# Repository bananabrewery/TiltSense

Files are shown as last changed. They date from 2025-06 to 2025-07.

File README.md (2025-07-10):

<div align="center">
  TiltSense
</div>

## TiltSense

**TiltSense** is a flexible and powerful ESP32-based system that brings together multiple sensors, integrations, and
user-friendly tools into a single customizable hub for fermentation monitoring.

After months of design, development, and testing, the first stable release is finally out of the oven — and it's packed
with features for homebrewers, hackers, and fermentation geeks alike.

🧪 The complete documentation is now available at:  
👉 [https://bananabrewery.github.io/TiltSense](https://bananabrewery.github.io/TiltSense)

---

## 📦 Project Status

TiltSense is stable and fully functional in its first release. The current firmware is offered as a complete example
configuration.

🛠️ **Ongoing development:**  
A **TiltSense Firmware Builder** is available — a web app that generates fully customized firmware tailored to your specific setup, eliminating manual editing.

- ✅ Which **Tilt hydrometers** are used, and their **colors**
- 🆚 Whether they are **Tilt** or **Tilt Pro** versions
- 🏠 Whether the user has **Home Assistant** integration
- 💨 Whether a **pressure sensor** is included
- 📡 Whether integration with **Brewfather** is desired

This simplifies setup and allows adapting TiltSense to a wide variety of fermentation scenarios.

Check out the Firmware Builder here:  
👉 [https://bananabrewery.github.io/TiltSenseFirmwareBuilder](https://bananabrewery.github.io/TiltSenseFirmwareBuilder)

I’ve also developed a backend compiler service that can build your firmware automatically — no local ESPHome install
needed!

---

## 🚀 Features

- **✅ Multi-Tilt Support**  
  Read and monitor multiple [Tilt Hydrometers](https://tilthydrometer.com/) simultaneously, including standard and Pro
  models.

- **📡 Brewfather & Home Assistant Integration**  
  Native support for seamless tracking, automation, and remote data logging.

- **🌐 Built-in Web Server**  
  Configure system parameters via an intuitive and mobile-friendly web interface.

- **🔀 Sensor Fusion**  
  Combine Tilt data with pressure sensors for real-time fermentation profiling (e.g., gravity curves under pressure).

- **🔋 Internal Battery**  
  Portable and continuous operation with low-power consumption and battery support.

- **🧲 Magnetic 3D-Printed Enclosure**  
  Custom-designed case with magnetic mounting — easy to use, easy to love.

- **💡 Touchscreen Interface**  
  Clean LVGL-powered display with gesture-based navigation, real-time feedback, and interactive widgets.

- **💰 Affordable & Accessible**  
  Built using low-cost, off-the-shelf ESP32 hardware and open-source components.

---

## 📷 Screenshots

<div align="center">
  TiltSense Screen
</div>

---

## 📦 Hardware Requirements

Here’s what you need to build a complete TiltSense unit:

- [**ESP32-S3 with 1.28" Round Touchscreen**
  (GC9A01A display + CST816S capacitive touch)](https://s.click.aliexpress.com/e/_oBHq2mi)  
  A compact, all-in-one ESP32-S3 development board with integrated round LCD and touchscreen.

- [**LiPo Battery 3.7V (1S) 200mAh with JST 1.25mm connector**](https://s.click.aliexpress.com/e/_op2Asqw)  
  Optional but supported.  
  ⚠️ **Important**: Check polarity before connecting. Some batteries come with inverted pins!

- [**M2xL2xOD3.2 Brass Heat-Set Inserts**](https://s.click.aliexpress.com/e/_okAnuHg)  
  For securing the case with threaded inserts.

- [**M2x5mm Screws**](https://s.click.aliexpress.com/e/_omZDYlo)  
  To mount the case and secure the board.

- [**Neodymium Magnet 20×3 mm**](https://s.click.aliexpress.com/e/_okD0ylg)  
  Embedded in the 3D-printed case for easy magnetic mounting on fermenters or fridges.

- [**3D-Printed Case**](https://makerworld.com/en/models/1509302-tiltsense#profileId-1580036)  
  A custom enclosure designed for easy assembly, battery integration, and magnetic mounting.  
  🖨️ **Print instructions are available
  on [MakerWorld](https://makerworld.com/en/models/1509302-tiltsense#profileId-1580036)**.

- [**USB-A to USB-C Cable**](https://s.click.aliexpress.com/e/_oCeMiAi)  
  For flashing firmware and charging the internal battery.

- **Pressure Sensor** *(optional — details coming soon)*  
  Used for advanced fermentation tracking by monitoring internal vessel pressure.

🖨️ Print instructions are available on [MakerWorld](https://makerworld.com/en/models/1509302-tiltsense#profileId-1580036)

---

## 🔧 Setup & Flashing

1. Configure and generate your custom firmware using the Firmware Builder:  
   👉 [https://bananabrewery.github.io/TiltSenseFirmwareBuilder/](https://bananabrewery.github.io/TiltSenseFirmwareBuilder/)

2. You can either:
    - Compile the firmware yourself using ESPHome, or
    - Use the backend compiler service integrated in the Firmware Builder to generate a ready-to-flash binary.

3. Flash your ESP32 using [ESPHome](https://web.esphome.io) with the firmware file.

4. Access the web UI via mDNS or IP (`http://tiltsense.local/`).

---

## 🤝 Integrations

- [Tilt Hydrometer](https://tilthydrometer.com/)
- [Brewfather](https://brewfather.app/)
- [Home Assistant](https://www.home-assistant.io/)

--- 

## 🛠️ Setup & Development Environment

### 1. Create a virtual environment

Make sure you have Python 3 installed. Then, in the root of the project, create a virtual environment:

```bash
python3 -m venv .venv
```

Activate the virtual environment:

```bash
source .venv/bin/activate
```

### 2. Install project dependencies

Once the virtual environment is active, install the required packages:

```bash
pip install -r requirements.txt
```

### 3. Serve the documentation (MkDocs)

To serve the documentation locally:

```bash
mkdocs serve
```

This will start a local server at:

```bash
http://127.0.0.1:8000/
```

MkDocs will automatically reload when you make changes to the documentation files.

### 4. Build the static site (optional)

To generate the static site in the site/ directory:

```bash
mkdocs build
```

This is useful if you want to deploy the documentation (e.g. to GitHub Pages).

---

## 🙋 Community & Support

- ❗ Report bugs or request features: [Open an issue](https://github.com/bananabrewery/TiltSense/issues)
- 💬 Share ideas and ask questions: [Join the discussion](https://github.com/bananabrewery/TiltSense/discussions)
- 🤝 Want to help? Contributions are welcome!

---

## 📝 License

This project is licensed under the [MIT License](LICENSE).

---

## ❤️ Acknowledgements

TiltSense is built with love using:

- [ESPHome](https://esphome.io/)
- [LVGL](https://lvgl.io/)
- [Tilt](https://tilthydrometer.com/)
- Community feedback and personal fermentation obsession 🧪🍻

Special thanks to [Llupols](https://github.com/llupols) for designing the TiltSense logo. Your creativity and talent
have given our project a unique identity. Much appreciated!

---

## 🙌 Contribute

Pull requests are welcome! Fork the repo, improve the code or docs, and open a PR.  
You can also contribute by sharing feedback or joining discussions.

---

## 📣 Stay tuned

More features, documentation, and exciting new hardware coming soon!

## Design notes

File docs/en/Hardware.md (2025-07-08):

---
title: Hardware Requirements
description: Complete list of components required to build a TiltSense device, including the ESP32-S3 board, battery, case, and accessories.
icon: material/cube
---

# Hardware Requirements

This section outlines the complete list of hardware components required to assemble a functional **TiltSense** device.
The chosen components are optimized for compactness, reliability, and ease of assembly, leveraging widely available and
affordable parts.

## Required Components

### 🔹 ESP32-S3 with 1.28" Round Touchscreen

[Buy on AliExpress](https://s.click.aliexpress.com/e/_oBHq2mi)

<div align="center">
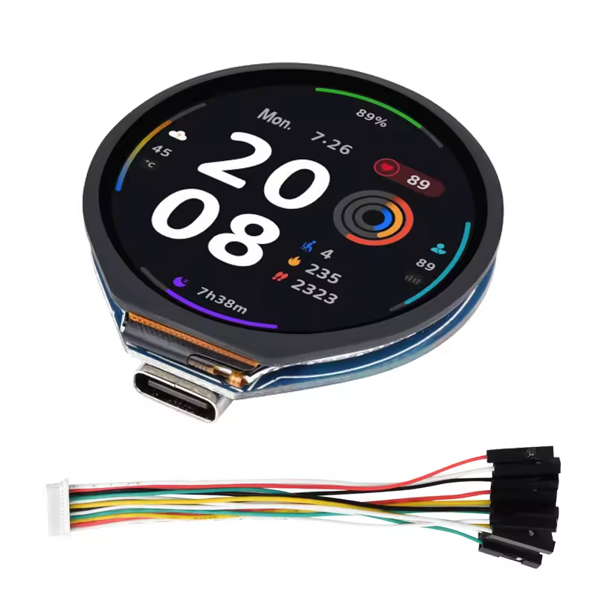
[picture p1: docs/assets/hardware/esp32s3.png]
TiltSense ESP32-S3
  
</div>

A compact, all-in-one ESP32-S3 development board featuring:

- A 1.28" round **GC9A01A** TFT LCD
- **CST816S** capacitive touch interface
- Onboard USB-C, charging circuitry, and GPIO access

> 📌 This is the core of the TiltSense system. Make sure your version includes both the GC9A01A display and CST816S touch
> controller.

For technical details, pinouts, and specifications, refer to the official Waveshare documentation:  
🔗 [ESP32-S3-Touch-LCD-1.28 — Waveshare Wiki](https://www.waveshare.com/wiki/ESP32-S3-Touch-LCD-1.28)

---

### 🔋 LiPo Battery – 3.7V (1S) 200mAh with JST 1.25mm Connector

[Buy on AliExpress](https://s.click.aliexpress.com/e/_op2Asqw)

<div align="center">
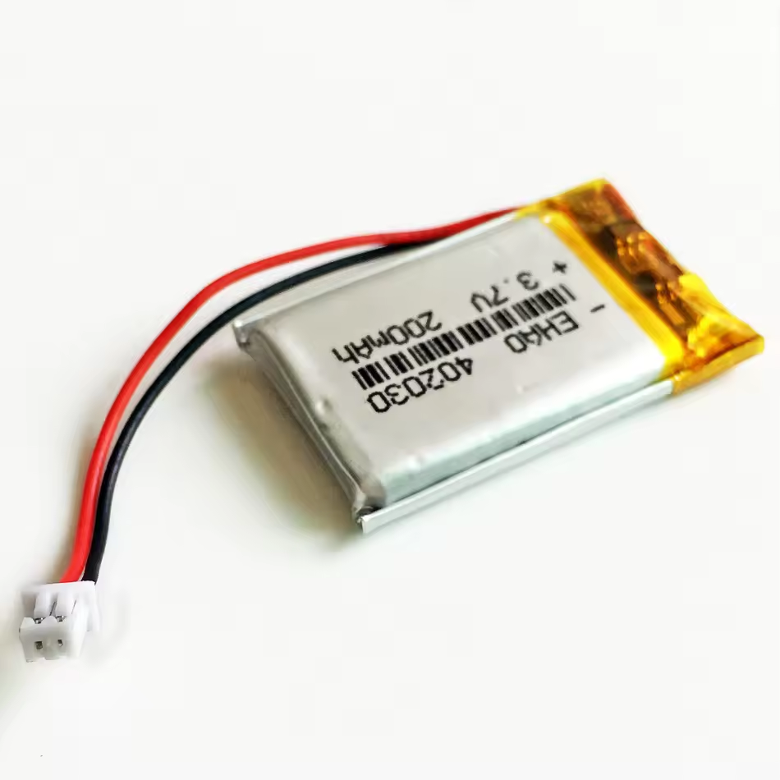
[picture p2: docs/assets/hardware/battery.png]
TiltSense Battery
  
</div>

A small rechargeable lithium battery that powers the device when disconnected from USB.

- Optional but supported
- Provides approx. 45 minutes of runtime
- Useful for safe relocation or in case of temporary power loss

> ⚠️ **Important**: Always verify **polarity** before connecting the battery. Some suppliers use inverted connectors
> which may damage the board.

---

### 🔩 M2 Brass Heat-Set Inserts

[Buy on AliExpress](https://s.click.aliexpress.com/e/_okAnuHg)

<div align="center">
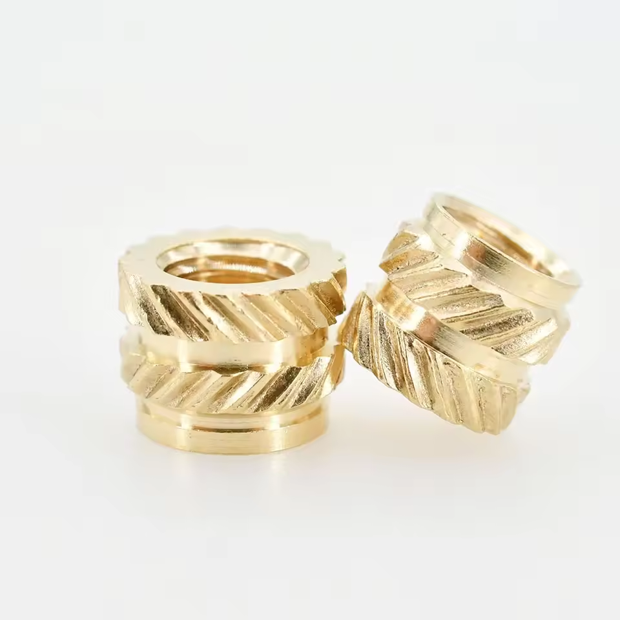
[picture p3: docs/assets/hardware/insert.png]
TiltSense M2 Insert
  
</div>

Heat-set inserts used to reinforce the mounting points of the 3D-printed enclosure:

- Dimensions: **M2 × L2 mm × OD3.2 mm**
- Installed with a soldering iron or insert tool

---

### 🔧 M2x5mm Screws

[Buy on AliExpress](https://s.click.aliexpress.com/e/_omZDYlo)

<div align="center">
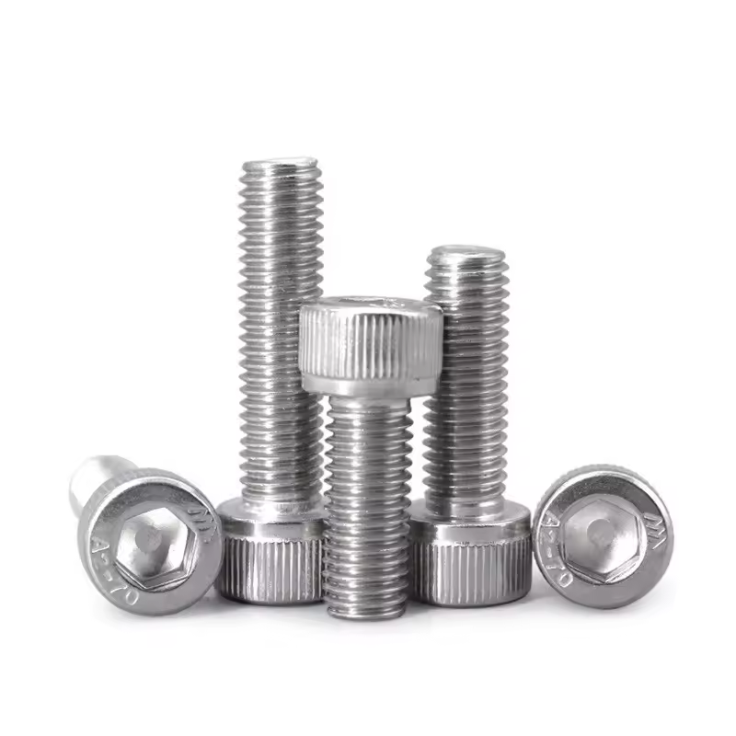
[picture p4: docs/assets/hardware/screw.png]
TiltSense Screw
  
</div>

Small metric screws to secure the ESP32 board to the case and fasten the enclosure parts.

---

### 🧲 Neodymium Magnet – 20×3mm

[Buy on AliExpress](https://s.click.aliexpress.com/e/_okD0ylg)

<div align="center">
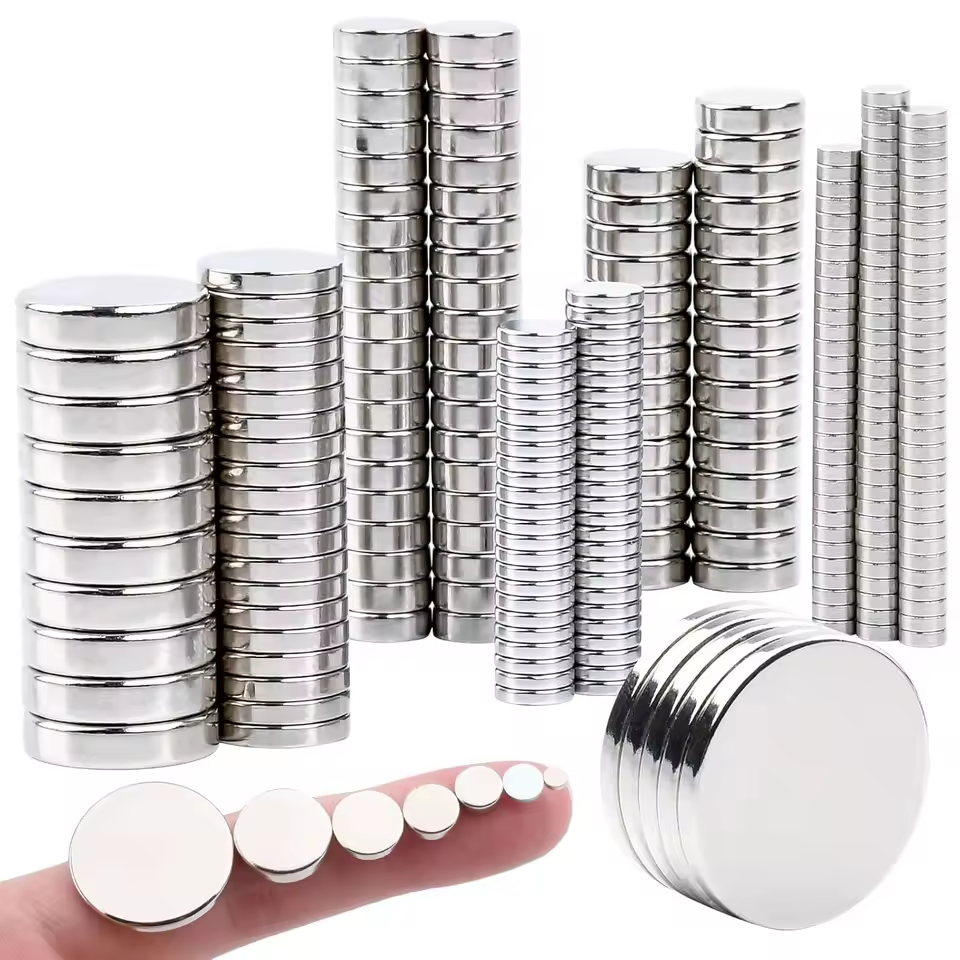
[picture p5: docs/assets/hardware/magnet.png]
TiltSense Magnet
  
</div>

A circular magnet embedded in the rear of the case, allowing the device to attach firmly to metal surfaces like
fermentation chambers or kegerators.

---

### 🖨️ 3D-Printed Enclosure

[Download from MakerWorld](https://makerworld.com/en/models/1509302-tiltsense#profileId-1580036)  
A custom-designed case optimized for:

- Easy insertion of the ESP32 board
- Battery compartment
- Magnetic mounting support

> Printing instructions and STL files are available on MakerWorld. Designed for standard FDM printers.

---

### 🔌 USB-A to USB-C Cable

[Buy on AliExpress](https://s.click.aliexpress.com/e/_oCeMiAi)

<div align="center">
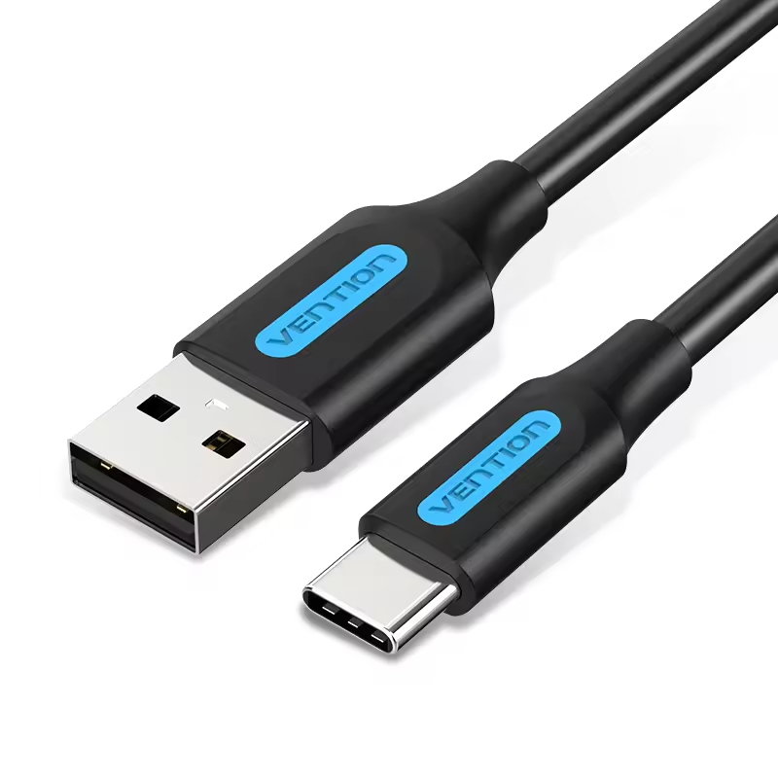
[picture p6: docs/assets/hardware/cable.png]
TiltSense USB Cable
  
</div>

Used to:

- Flash the firmware using the TiltSense Web Builder
- Charge the internal battery when connected to a power source
- Keep TiltSense connected for long-term use, such as monitoring the entire fermentation process.

---

## Optional Components

### 📈 Pressure Sensor *(Optional — full documentation coming soon)*

TiltSense already supports pressure monitoring via **external sensors integrated through Home Assistant**. This allows
advanced fermentation profiling by combining gravity data with real-time pressure readings.

A dedicated pressure sensor module — designed and tested by **Banana Brewery** — is already developed and fully
functional. Detailed documentation covering its **assembly, wiring, and configuration** will be published soon as an
official expansion to the TiltSense ecosystem.

---

## Additional Tools

To assemble TiltSense, you may also need:

- A **soldering iron** (for heat-set inserts or wiring mods)
- **M2 hex driver or screwdriver**
- **Double-sided tape**, hot glue, or a small piece of soft foam *(optional, for securing the battery)*  
  To prevent the battery from shifting inside the case, you can use adhesive or insert a small cut of soft, lightweight
  foam to hold it gently in place without pressure on the wiring.

---

## Notes

- The components listed here are suggestions based on tested and validated builds.
- Availability may vary by region; equivalent parts from other vendors are valid as long as specifications match.
- Always double-check voltage and polarity before connecting components, especially batteries and external sensors.

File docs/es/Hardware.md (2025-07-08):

---
title: Requisitos de Hardware
description: Lista completa de componentes necesarios para construir un dispositivo TiltSense, incluyendo la placa ESP32-S3, batería, carcasa y accesorios.
icon: material/cube
---

# Requisitos de Hardware

Esta sección describe la lista completa de componentes necesarios para ensamblar un dispositivo **TiltSense**
funcional. Los componentes seleccionados están optimizados para ser compactos, fiables y fáciles de montar, utilizando
piezas
asequibles y ampliamente disponibles.

## Componentes Necesarios

### 🔹 ESP32-S3 con pantalla táctil circular de 1.28"

[Comprar en AliExpress](https://s.click.aliexpress.com/e/_oBHq2mi)

<div align="center">
  TiltSense ESP32-S3
</div>

Una placa de desarrollo ESP32-S3 todo en uno que incluye:

- Pantalla TFT LCD circular de **1.28"** con chip **GC9A01A**
- Pantalla táctil capacitiva con controlador **CST816S**
- USB-C integrado, circuito de carga y acceso a pines GPIO

> 📌 Este es el núcleo del sistema TiltSense. Asegúrate de que tu versión incluya tanto la pantalla GC9A01A como el
> controlador táctil CST816S.

Para más detalles técnicos, esquemas de pines y especificaciones, consulta la documentación oficial de Waveshare:  
🔗 [ESP32-S3-Touch-LCD-1.28 — Waveshare Wiki](https://www.waveshare.com/wiki/ESP32-S3-Touch-LCD-1.28)

---

### 🔋 Batería LiPo – 3.7V (1S) 200mAh con conector JST 1.25mm

[Comprar en AliExpress](https://s.click.aliexpress.com/e/_op2Asqw)

<div align="center">
  Batería TiltSense
</div>

Pequeña batería de litio recargable que alimenta el dispositivo cuando no está conectado por USB.

- Es opcional pero tiene soporte
- Proporciona aproximadamente 45 minutos de autonomía
- Útil para mover el dispositivo o en caso de cortes de energía temporales

> ⚠️ **Importante**: Verifica siempre la **polaridad** antes de conectar la batería. Algunos proveedores utilizan
> conectores invertidos que podrían dañar la placa.

---

### 🔩 Inserciones roscadas M2 de latón (Heat-Set)

[Comprar en AliExpress](https://s.click.aliexpress.com/e/_okAnuHg)

<div align="center">
  Inserto M2 TiltSense
</div>

Inserciones roscadas para reforzar los puntos de anclaje de la carcasa impresa en 3D:

- Dimensiones: **M2 × L2 mm × OD3.2 mm**
- Se instalan con un soldador o herramienta de inserción térmica

---

### 🔧 Tornillos M2x5mm

[Comprar en AliExpress](https://s.click.aliexpress.com/e/_omZDYlo)

<div align="center">
  Tornillo TiltSense
</div>

Tornillos métricos pequeños para fijar la placa ESP32 a la carcasa y unir las partes del dispositivo.

---

### 🧲 Imán de Neodimio – 20×3mm

[Comprar en AliExpress](https://s.click.aliexpress.com/e/_okD0ylg)

<div align="center">
  Imán TiltSense
</div>

Imán cilíndrico insertado en la parte trasera de la carcasa, que permite fijar el dispositivo firmemente sobre
superficies
metálicas como fermentadores o neveras.

---

### 🖨️ Carcasa impresa en 3D

[Descargar desde MakerWorld](https://makerworld.com/en/models/1509302-tiltsense#profileId-1580036)  
Carcasa personalizada diseñada para:

- Inserción sencilla de la placa ESP32
- Compartimento para batería
- Soporte para montaje magnético

> Las instrucciones de impresión y los archivos STL están disponibles en MakerWorld. Diseñada para impresoras FDM
> estándar.

---

### 🔌 Cable USB-A a USB-C

[Comprar en AliExpress](https://s.click.aliexpress.com/e/_oCeMiAi)

<div align="center">
  Cable USB TiltSense
</div>

Usado para:

- Flashear el firmware usando TiltSense Web Builder
- Cargar la batería interna
- Mantener TiltSense alimentado durante todo el proceso de fermentación

---

## Componentes Opcionales

### 📈 Sensor de Presión *(Opcional — documentación próximamente)*

TiltSense ya soporta monitorización de presión a través de **sensores externos integrados mediante Home Assistant**.
Esto permite un perfilado avanzado de la fermentación combinando lecturas de densidad y presión en tiempo real.

Un módulo de sensor de presión — diseñado y probado por **Banana Brewery** — ya está desarrollado y completamente
funcional. Se publicará próximamente la documentación detallada sobre su **montaje, cableado y configuración** como
expansión oficial del ecosistema TiltSense.

---

## Herramientas Adicionales

Para ensamblar TiltSense, también puedes necesitar:

- Un **soldador** (para insertar los heat-sets o hacer modificaciones)
- **Destornillador o punta hexagonal M2**
- **Cinta de doble cara**, silicona caliente o un trozo pequeño de espuma blanda *(opcional, para sujetar la batería)*  
  Para evitar que la batería se desplace dentro de la carcasa, puedes usar adhesivo o insertar un trozo de espuma blanda
  y ligera para mantenerla en su sitio sin ejercer presión sobre el cableado.

---

## Notas

- Los componentes aquí listados están basados en montajes ya probados y verificados.
- La disponibilidad puede variar según la región; se podrían usar piezas equivalentes si coinciden con las
  especificaciones.
- Verifica siempre el voltaje y la polaridad antes de conectar componentes, especialmente baterías y sensores externos.

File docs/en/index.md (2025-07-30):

---
title: Welcome to TiltSense
description: Explore the official documentation of TiltSense — a powerful, customizable, and open-source fermentation monitoring system based on ESP32.
icon: material/home
---

<div align="center">
  TiltSense
</div>

# Welcome to the TiltSense Wiki

## Contents

- [Home](index.md)
- [Hardware Requirements](Hardware.md)
- [Assembly Instructions](Assembly.md)
- [Firmware Configuration and Installation](Firmware-Setup.md)
- [Device Usage and Features](Usage.md)
- [Development and Contributions](Development.md)
- [Frequently Asked Questions (FAQ)](FAQ.md)
- [Credits and Acknowledgements](Credits.md)

---

## What is TiltSense?

TiltSense is an advanced, flexible, and user-friendly fermentation monitoring system built around the powerful ESP32
microcontroller platform. It is designed specifically for homebrewers, fermentation hobbyists, and experimental brewers
who want to track their fermentation processes with precision and ease.

At its core, TiltSense reads data from multiple Tilt Hydrometers—both standard and Pro models—allowing simultaneous
monitoring of several fermenters. Beyond gravity readings, it supports additional sensors such as pressure sensors,
providing deeper insights into fermentation dynamics like pressure changes inside fermenting vessels.

One of TiltSense’s key strengths is its customizable firmware, which users can generate and tailor easily to their
specific hardware setup and integration preferences using the TiltSense Firmware Builder — a web application that
removes the complexity of manual configuration.

TiltSense integrates seamlessly with popular fermentation and automation platforms such as Brewfather and Home
Assistant, enabling remote data visualization, automation, and logging.

With its intuitive touchscreen interface housed in a compact, 3D-printed magnetic case, TiltSense combines portability,
ease of use, and advanced functionality into a single device that fits perfectly into any homebrew setup.

To get started, check out the sections below for detailed hardware lists, assembly instructions, firmware configuration,
and more!

---

## Features

### ✅ Multi-Tilt Hydrometer Support

TiltSense is capable of detecting and monitoring multiple [Tilt Hydrometers](https://tilthydrometer.com/)
simultaneously — including both **standard** and **Pro** models — across different fermenters. Each hydrometer’s data is
independently processed and displayed, allowing accurate real-time tracking of specific gravity and temperature for
multiple batches in parallel.

### 📡 Native Integration with Brewfather & Home Assistant

Seamless integration with **Brewfather** and **Home Assistant** enables automated data logging, visualization, and
advanced brewing workflows. TiltSense supports API-based communication with these platforms, requiring no additional
configuration once network parameters are set.

### 🌐 Built-in Web Configuration Interface

The device hosts a fully responsive, built-in web interface accessible from any browser on the local network. Users can
configure firmware settings, enabled sensors, data publishing endpoints, and more — without needing
to reflash or access the firmware directly.

### 🔀 Pressure Sensor Integration

TiltSense supports **pressure sensor** readings, combining gravity data from Tilt Hydrometers with optional pressure
sensors. This allows brewers to analyze fermentation dynamics such as pressure curves and pressure-compensated gravity
estimates, providing deeper insight into closed or pressurized fermentations.

### 🔋 Internal Battery Support

TiltSense features a compact Li-Po backup battery providing short-term power autonomy (~45 minutes). This is
intended for temporary mobility, system reboots, or brief outages — acting as a lightweight integrated UPS for safe
transitions and power resilience.

### 🧲 Custom Magnetic 3D-Printed Enclosure

The physical casing is designed specifically for practical use in brewing environments:

- Compact and durable
- 3D-printable with standard FDM printers
- Integrated magnets for easy mounting on fermentation chambers, kegerators, or metal surfaces

All case designs are open-source and fully customizable.

### 💡 Intuitive Touchscreen Interface

The device includes a high-resolution capacitive touchscreen powered by **LVGL** (Light and Versatile Graphics Library).
Users can interact with a clean, real-time display featuring gravity plots, sensor status, visual alerts, and
swipe-based navigation.

### 💰 Cost-Effective

TiltSense is built entirely from affordable, off-the-shelf components based on the ESP32 platform. This makes it an
ideal low-cost solution for those looking for functionality without high expenses.

### 🛠️ Fully Open Source

The firmware, web interface, 3D-printed enclosure, and configuration tools are all fully open source. This ensures
accessibility for makers, brewers, and developers — without license fees or vendor lock-in.

---

## Next Steps

### TiltSense Max

We're adding support for a new device based on the same ESP32-S3 architecture, but equipped with a much larger display
and double the screen resolution. Once ESPHome adds chart support for LVGL, this screen will offer a wide range of
options — including visualizing gravity and temperature readings during fermentation, directly on the TiltSense device.

### ESPHome Improvements

We're implementing enhancements made possible by ESPHome, such as:

- Improved web interface
- Better touch responsiveness
- Optimized code performance

### New TiltSense Satellites: Pressure Sensor and Valve

Two new modules are already developed and currently being tested in real-world scenarios. Full documentation and
open-source details will be shared soon.

- **Pressure Sensor:** Monitors fermentation pressure in real time and allows you to set a target value. The pressure
  valve will automatically accumulate or release pressure based on this setting.
- **Pressure Valve:** A simple actuator that opens or closes to release excess pressure from the fermentation vessel
  when needed.

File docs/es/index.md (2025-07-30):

---
title: Bienvenido a TiltSense
description: Explora la documentación oficial de TiltSense — un sistema de monitorización de fermentaciones potente, personalizable y de código abierto basado en ESP32.
icon: material/home
---

<div align="center">
  TiltSense
</div>

# Bienvenido a la Wiki de TiltSense

## Contenidos

- [Inicio](index.md)
- [Requisitos de Hardware](Hardware.md)
- [Instrucciones de Montaje](Assembly.md)
- [Configuración e Instalación del Firmware](Firmware-Setup.md)
- [Uso del Dispositivo y Funcionalidades](Usage.md)
- [Desarrollo y Contribuciones](Development.md)
- [Preguntas Frecuentes (FAQ)](FAQ.md)
- [Créditos y Agradecimientos](Credits.md)

---

## ¿Qué es TiltSense?

TiltSense es un sistema avanzado, flexible y fácil de usar para la monitorización de la actividad en las fermentaciones,
construido sobre la potente plataforma ESP32. Está diseñado específicamente para homebrewers, aficionados a la
fermentación y cerveceros experimentales que deseen obtener información en tiempo real sobre sus procesos de
fermentación con precisión y comodidad.

En esencia, TiltSense lee datos de múltiples Tilt Hydrometers — tanto modelos estándar como Pro — permitiendo la
monitorización simultánea de varios fermentadores. Además de las lecturas de densidad, también admite sensores
adicionales como sensores de presión, proporcionando una visión más profunda de las dinámicas de fermentación, como los
cambios de presión dentro del fermentador.

Una de las grandes fortalezas de TiltSense es su firmware personalizable, que los usuarios pueden generar y adaptar
fácilmente a su configuración de hardware e integraciones preferidas mediante el generador de firmware TiltSense
Firmware Builder — una aplicación web que elimina la complejidad de la configuración manual.

TiltSense se integra perfectamente con plataformas populares de fermentación y automatización como Brewfather y Home
Assistant, permitiendo visualización remota de datos, automatización y registro de eventos.

Con una interfaz táctil intuitiva integrada en una carcasa magnética compacta impresa en 3D, TiltSense combina
portabilidad, facilidad de uso y funcionalidades avanzadas en un solo dispositivo ideal para cualquier setup
homebrewing.

Para empezar, consulta las secciones siguientes con listas de hardware detalladas, instrucciones de montaje,
configuración de firmware ¡y mucho más!

---

## Funcionalidades

### ✅ Soporte Multi-Tilt Hydrometer

TiltSense es capaz de detectar y monitorizar múltiples [Tilt Hydrometers](https://tilthydrometer.com/) simultáneamente —
incluyendo modelos **estándar** y **Pro** — en distintos fermentadores. Los datos de cada hidrómetro se procesan y
muestran de forma independiente, permitiendo un seguimiento en tiempo real y con precisión de la densidad y temperatura
de varios lotes en paralelo.

### 📡 Integración Nativa con Brewfather y Home Assistant

La integración con **Brewfather** y **Home Assistant** permite el registro automático de datos, visualización y flujos
de trabajo avanzados para la elaboración. TiltSense se comunica con estas plataformas mediante API, sin necesidad de
configuración adicional una vez establecida la conexión de red.

### 🌐 Interfaz Web de Configuración Integrada

El dispositivo aloja una interfaz web totalmente responsiva a la que se puede acceder desde cualquier navegador en la
red local. Los usuarios pueden configurar ajustes del firmware, sensores habilitados, destinos de publicación de datos y
más — sin necesidad de volver a flashear el firmware ni modificarlo manualmente.

### 🔀 Integración con Sensores de Presión

TiltSense admite **lecturas de presión**, combinando los datos de densidad de los Tilt Hydrometers con sensores
de presión opcionales. Esto permite a los cerveceros analizar dinámicas de fermentación como curvas de presión y
estimaciones de densidad corregidas por presión, ofreciendo una visión más completa de fermentaciones isobáricas.

### 🔋 Batería Interna Integrada

TiltSense cuenta con una batería interna compacta Li-Po que proporciona autonomía a corto plazo (~45 minutos).
Está pensada para movilidad temporal, reinicios del sistema o cortes breves de energía — actuando como un mini SAI
integrado para transiciones seguras y resiliencia ante fallos de alimentación.

### 🧲 Carcasa Magnética Impresa en 3D

La carcasa física ha sido diseñada específicamente para un uso práctico en entornos cerveceros:

- Compacta y resistente
- Imprimible en 3D con impresoras FDM estándar
- Imanes integrados para un montaje fácil en cámaras de fermentación, kegerators o superficies metálicas.

Todos los diseños de carcasa son de código abierto y completamente personalizables.

### 💡 Interfaz Táctil Intuitiva

El dispositivo incluye una pantalla táctil capacitiva de alta resolución, impulsada por **LVGL** (Light and Versatile
Graphics Library). Los usuarios pueden interactuar con una interfaz clara y en tiempo real con gráficos de densidad,
estado de sensores, alertas visuales y navegación mediante deslizamiento.

### 💰 Económico

TiltSense está construido íntegramente con componentes asequibles y fácilmente disponibles basados en la plataforma
ESP32. Esto lo convierte en una solución de bajo coste ideal para quienes buscan funcionalidad sin grandes inversiones.

### 🛠️ Totalmente Open Source

El firmware, la interfaz web, la carcasa impresa en 3D y las herramientas de configuración son completamente de código
abierto. Esto garantiza accesibilidad para makers, cerveceros y desarrolladores — sin licencias ni ataduras.

---

## Próximos pasos

### TiltSense Max

Estamos añadiendo soporte para un nuevo dispositivo basado en la misma arquitectura ESP32-S3, pero equipado con una
pantalla mucho más grande y con el doble de resolución. En cuanto ESPHome incorpore compatibilidad con gráficos en LVGL,
esta pantalla ofrecerá un amplio abanico de opciones — incluyendo la visualización de los valores de densidad y
temperatura durante la fermentación, directamente en el dispositivo TiltSense.

### Mejoras en ESPHome

Estamos implementando mejoras gracias a las capacidades de ESPHome, como por ejemplo:

- Interfaz web mejorada
- Mayor sensibilidad táctil
- Optimización del rendimiento del código

### Nuevos satélites TiltSense: Sensor de Presión y Válvula

Dos nuevos módulos ya están desarrollados y se están probando en escenarios reales. Muy pronto se compartirá toda la
documentación e información como proyecto abierto.

- **Sensor de Presión:** Monitoriza la presión durante la fermentación en tiempo real y permite configurar un valor
  objetivo. La válvula de presión acumulará o liberará presión automáticamente en función de este valor.
- **Válvula de Presión:** Actuador simple que abre o cierra la válvula para liberar el exceso de presión del fermentador
  cuando sea necesario.

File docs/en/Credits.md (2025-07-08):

---
title: Credits and Acknowledgements
description: Recognition for the technologies, people, and communities that made the TiltSense project possible.
icon: material/heart-circle
---

# Credits and Acknowledgements

TiltSense is the result of many months of dedication, testing, and collaboration within the fermentation and maker communities. This project would not be possible without the support and inspiration of numerous people and tools.

## Core Technologies and Libraries

- [Tilt Hydrometer](https://tilthydrometer.com/)  
  The core sensor technology for fermentation gravity monitoring.

- [ESPHome](https://esphome.io/)  
  The amazing framework that powers the TiltSense firmware and enables easy ESP32 integration.

- [LVGL (Light and Versatile Graphics Library)](https://lvgl.io/)  
  Provides the clean, responsive touchscreen interface for TiltSense.

- [Brewfather](https://brewfather.app/)  
  Integration platform for fermentation and brew tracking.

- [Home Assistant](https://www.home-assistant.io/)  
  Home automation and monitoring platform, integrated for remote data visualization.

## Design and Artwork

<div align="center">
  TiltSense
</div>

- Special thanks to [Llupols](https://github.com/llupols) for designing the unique TiltSense logo and branding, which give the project its distinctive identity.

## Community and Feedback

- Thanks to the homebrewing and maker communities whose feedback has guided development and testing.

- All fermentation geeks and experimental brewers who inspire continuous improvement. 🧪🍻

## Contributors

TiltSense is an open-source project, and we are deeply grateful to the people who help bring it to life.

- **[@bananabrewery](https://github.com/bananabrewery)** — Principal developer and project maintainer

More contributors will be added as the project evolves. If you’d like to get involved, check out the [Development and Contributions](Development.md) section.

## Additional Thanks

- Contributors and beta testers who have helped identify issues and improve features.

- Open-source developers and maintainers whose tools and libraries made this project achievable.

---

Thank you for supporting TiltSense!  
If you'd like to contribute or share feedback, please visit our [GitHub repository](https://github.com/bananabrewery/TiltSense).

---

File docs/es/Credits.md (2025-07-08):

---
title: Créditos y Agradecimientos
description: Reconocimiento a las tecnologías, personas y comunidades que han hecho posible el desarrollo de TiltSense.
icon: material/heart-circle
---

# Créditos y Agradecimientos

TiltSense es el resultado de muchos meses de dedicación, pruebas y colaboración dentro de las comunidades de fermentación y makers. Este proyecto no sería posible sin el apoyo e inspiración de numerosas personas y herramientas.

## Tecnologías y Librerías Principales

- [Tilt Hydrometer](https://tilthydrometer.com/)  
  La tecnología principal del sensor para monitorizar la gravedad de la fermentación.

- [ESPHome](https://esphome.io/)  
  El increíble framework que impulsa el firmware de TiltSense y facilita la integración con ESP32.

- [LVGL (Light and Versatile Graphics Library)](https://lvgl.io/)  
  Proporciona la interfaz táctil limpia y responsiva para TiltSense.

- [Brewfather](https://brewfather.app/)  
  Plataforma de integración para el seguimiento de la fermentación y la elaboración.

- [Home Assistant](https://www.home-assistant.io/)  
  Plataforma de automatización y monitorización del hogar, integrada para visualización remota de datos.

## Diseño y Arte

<div align="center">
  TiltSense
</div>

- Agradecimientos especiales a [Llupols](https://github.com/llupols) por diseñar el logo y la imagen de marca únicos de TiltSense, que le dan al proyecto su identidad distintiva.

## Comunidad y Feedback

- Gracias a las comunidades de homebrewers y makers, cuyo feedback ha guiado el desarrollo y las pruebas.

- A todos los geeks de la fermentación y cerveceros experimentales que inspiran la mejora continua. 🧪🍻

## Contribuciones

TiltSense es un proyecto open-source, y estamos especialmente agradecidos a todas las personas que han ayudado a hacerlo una realidad.

- **[@bananabrewery](https://github.com/bananabrewery)** — Desarrollador principal y encargado del mantenimiento del proyecto

Se añadirán más colaboradores a medida que el proyecto evolucione. Si quieres participar, consulta la sección de [Desarrollo y Contribuciones](Development.md).

## Agradecimientos Adicionales

- A los colaboradores y beta testers que han ayudado a identificar problemas y mejorar funcionalidades.

- A los desarrolladores y mantenedores de software open source, cuyas herramientas y librerías han hecho posible este proyecto.

---

¡Gracias por apoyar TiltSense!  
Si quieres contribuir o compartir tu feedback, visita nuestro [repositorio en GitHub](https://github.com/bananabrewery/TiltSense).

---

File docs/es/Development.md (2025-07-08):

---
title: Desarrollo y Contribuciones
description: Guía e información para desarrolladores y colaboradores interesados en mejorar TiltSense.
icon: material/code-tags
---

# Desarrollo y Contribuciones

TiltSense es un proyecto de código abierto construido con la pasión y colaboración de las comunidades cervecera y maker.
Damos la bienvenida a todo tipo de contribuciones — mejoras de código, documentación, diseño de hardware, reportes de
errores, sugerencias de funcionalidades y más.

## Primeros Pasos

Si quieres contribuir, aquí tienes cómo empezar:

- **Haz un fork del repositorio** en GitHub: [TiltSense en GitHub](https://github.com/bananabrewery/TiltSense)
- **Clona tu fork localmente** y configura el entorno de desarrollo.
- **Crea una nueva rama** para tu funcionalidad o corrección.
- **Haz tus cambios** con mensajes de commit claros y concisos.
- **Prueba tu código**, especialmente si afecta al firmware o hardware.
- **Envía un Pull Request (PR)** con una descripción detallada de tu trabajo.

## Reporte de Errores

¿Has encontrado un error o tienes una petición de mejora? Por favor, repórtalo en la **sección de Issues** del
repositorio de GitHub:

👉 [https://github.com/bananabrewery/TiltSense/issues](https://github.com/bananabrewery/TiltSense/issues)

Proporciona el mayor nivel de detalle posible, incluyendo pasos para reproducir el error, logs, capturas de pantalla o
ejemplos YAML si es relevante.

## Comunidad y Discusiones

¿Tienes una duda, quieres proponer una idea o simplemente conectar con otros usuarios? Únete a la comunidad en la **sección de Discussions**:

💬 [https://github.com/bananabrewery/TiltSense/discussions](https://github.com/bananabrewery/TiltSense/discussions)

Damos la bienvenida a preguntas, publicaciones de proyectos, sugerencias y colaboraciones.

## Guía para Contribuir

- Sigue el estilo de código y la estructura existente del proyecto.
- Actualiza o añade documentación cuando sea necesario.
- Escribe código claro, mantenible y probado cuando aplique.
- Intenta mantener los Pull Requests enfocados y limitados a una sola funcionalidad siempre y cuando sea posible.

## Agradecimientos

TiltSense no existiría sin el increíble ecosistema de código abierto y el apoyo de sus colaboradores. Gracias por
ayudarnos a hacer la fermentación más inteligente, transparente y accesible.

---

*Esperamos tus ideas, tu código y tus comentarios. ¡Construyamos algo increíble juntos!*

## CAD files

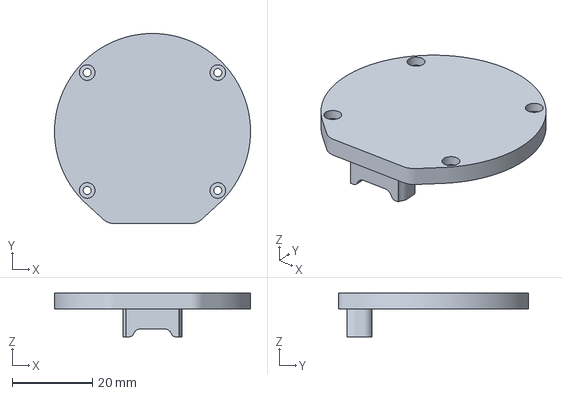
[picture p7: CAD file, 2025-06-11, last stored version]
hardware/stl/TiltSense Lid v1.3MF
48.9 x 47.4 x 10.9 mm

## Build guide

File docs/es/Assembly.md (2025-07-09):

---
title: Instrucciones de Montaje
description: Guía paso a paso para montar el dispositivo TiltSense, incluyendo instalación de la placa, configuración de la batería y cierre de la carcasa.
icon: material/screwdriver
---

# Instrucciones de Montaje

Esta sección te guiará a través del proceso completo de montaje del hardware de TiltSense. La carcasa impresa en 3D está
diseñada para un ensamblaje preciso y sin apenas herramientas. Tras seguir unos pasos muy básicos, tu dispositivo estará
listo para la instalación del firmware y su posterior uso en fermentaciones.

> 🛑 **Importante:** Antes de empezar, asegúrate de haber revisado los [Requisitos de Hardware](Hardware.md) y de tener
> todos los componentes listos.

---

## Instrucciones Paso a Paso

### 1. Instalar los Inserts Roscados

Con la ayuda un soldador caliente, instala cuidadosamente los **cuatro inserts roscados de latón** en los orificios
destinados para ello en la carcasa impresa en 3D. Aplica una ligera presión hacia abajo hasta que el insert quede
totalmente integrado en el plástico. Deja que se enfríe por completo antes de continuar.

> 🔥 Consejo: Usa una punta especial para inserts roscados o una punta plana del soldador para obtener mejores
> resultados.

---

### 2. Colocar la Placa ESP32-S3

Inserta la placa ESP32-S3 en la carcasa, alineando el **puerto USB-C** con la abertura correspondiente. Presiona
suavemente la placa hasta que encaje completamente en el fondo, asegurándote de que **la pantalla quede
perfectamente alineada y encajada en el bisel frontal**.

---

### 3. (Opcional) Conectar y Colocar la Batería

Si vas a usar una batería LiPo, conéctala al conector JST de 1.25 mm en la placa, verificando la **polaridad** antes de
conectar. Coloca la batería sobre la placa ESP32-S3, asegurándote de que no obstruya el conector USB-C.

---

### 4. (Opcional) Añadir Espuma para Fijar la Batería

Para evitar movimiento durante el manejo, coloca un pequeño trozo de **espuma suave y ligera** al lado o encima de la
batería. Esto proporciona una presión leve que mantiene la batería estable y fija sin forzar el cableado.

---

### 5. Colocar la Tapa

Alinea la tapa con la carcasa y presiónala suavemente en su lugar. La tapa está diseñada para **asegurar la placa
ESP32-S3 desde el lado del puerto USB-C**, manteniéndola fija incluso durante el movimiento.

---

### 6. Asegurar la Carcasa con Tornillos

Inserta los **tornillos M2x5mm** en los orificios de montaje y apriétalos hasta que queden firmes. No aprietes en exceso
para evitar dañar el plástico o los propios inserts.

---

## ¡Montaje Terminado!

Tu dispositivo TiltSense está completamente ensamblado y listo para la carga del firmware y su configuración. Continúa
con la sección de [Configuración e Instalación del Firmware](Firmware-Setup.md) para completar el proceso.

> 🧪 Antes de cerrar la carcasa, quizá te interese cargar el firmware usando el puerto USB-C para evitar tener que volver
> a abrirla. Durante el proceso de carga, puede que necesites presionar y mantener el botón Boot en la placa ESP32-S3 para
> habilitar el modo de programación.

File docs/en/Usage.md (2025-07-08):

---
title: Device Usage and Features
description: Learn how to interact with the TiltSense touchscreen interface and explore the features that make fermentation monitoring simple and efficient.
icon: material/gesture-tap-button
glightbox: false
---

# Device Usage and Features

<div align="center">
  TiltSense Screen
</div>

TiltSense offers a clean, intuitive, and fully touch-based interface for monitoring and managing your active
fermentations. This section explains how to use the device and outlines the main features available in the current
firmware version.

---

## 👆 Touchscreen Navigation

The TiltSense display is fully capacitive and responds to light finger taps. The screen is divided into **three main
interactive zones**:

<div align="center">
  TiltSense Screen
</div>
- **Left section** — Tap to navigate to the **previous Tilt** in the list.
- **Right section** — Tap to navigate to the **next Tilt**.
- **Bottom section** — Tap to **enable or disable** the selected Tilt device.

This allows fast and intuitive switching between hydrometers without needing buttons or menus.

---

## ⚙️ Core Functionality

### 📡 Sensor Readings

- When a Tilt device is **enabled**, the screen displays its live readings:
    - **Gravity (SG)**
    - **Temperature (°C or °F)**

- Sensor data is updated every **5 seconds** to optimize device performance and minimize processing load.

- If pressure monitoring is configured via **Home Assistant integration**, and linked to the selected Tilt, a **pressure
  reading** is also shown alongside gravity and temperature.

<div align="center">
  TiltSense Screen
</div>

### 💤 Sleep Mode

- The screen will automatically enter **sleep mode** after **2 minutes of inactivity** to reduce power consumption.
- To wake the screen, simply **tap anywhere**. The device will return to the same screen it was displaying before sleep.

### 📴 Enabling / Disabling Tilt Devices

- Tapping the **bottom section** of the screen toggles the selected Tilt between **enabled** and **disabled**.
- When disabled:
    - The Tilt is excluded integration updates.
    - No data is sent to Brewfather or Home Assistant.
    - The UI shows the Tilt color as **grayed out** to indicate its inactive state.

<div align="center">
  TiltSense Screen
</div>

This feature is useful when a Tilt is not in use or is powered off, helping to reduce system workload.

---

## 🔁 Brewfather Integration

- When Brewfather integration is enabled and configured, TiltSense transmits sensor data every **15 minutes**, following
  Brewfather’s official specification.

---

## 🏠 Home Assistant Integration

If the Home Assistant integration is enabled, TiltSense leverages the native capabilities
of [ESPHome](https://esphome.io/) to send real-time sensor data directly to Home Assistant.

This allows users to:

- **Monitor fermentation in real time** through Home Assistant dashboards.
- **Create automations or alerts** based on gravity, temperature, or pressure readings.
- **Combine Tilt data with other sensors**, such as temperature probes, pressure sensors, or smart plugs.

No additional configuration is needed on the device side beyond enabling ESPHome integration in Home Assistant — all
sensor data will be available as native entities.

---

TiltSense is designed for simplicity and responsiveness — enabling brewers to get a quick view of their fermentation
status at a glance, with minimal interaction.

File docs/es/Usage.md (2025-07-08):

---
title: Uso del Dispositivo y Funcionalidades
description: Aprende a interactuar con la interfaz táctil de TiltSense y explora las funciones que hacen que el seguimiento de la fermentación sea sencillo y eficiente.
icon: material/gesture-tap-button  
glightbox: false
---

# Uso del Dispositivo y Funcionalidades

<div align="center">
  Pantalla de TiltSense
</div>

TiltSense ofrece una interfaz limpia, intuitiva y completamente táctil para monitorizar y gestionar tus fermentaciones
activas. Esta sección explica cómo utilizar el dispositivo y describe las principales funciones disponibles en la
versión actual del firmware.

---

## 👆 Navegación Táctil

La pantalla de TiltSense es totalmente capacitiva y responde a toques suaves con el dedo. Está dividida en **tres zonas
interactivas principales**:

<div align="center">
  Interacciones en pantalla de de TiltSense
</div>

- **Zona izquierda** — Toca para navegar al **Tilt anterior** de la lista.
- **Zona derecha** — Toca para navegar al **siguiente Tilt**.
- **Zona inferior** — Toca para **activar o desactivar** el Tilt seleccionado.

Esto permite cambiar rápidamente entre Tilts de forma intuitiva, sin necesidad de botones ni menús.

---

## ⚙️ Funcionalidades Principales

### 📡 Lectura de Sensores

- Cuando un dispositivo Tilt está **activado**, la pantalla muestra sus lecturas en tiempo real:
    - **Densidad (SG)**
    - **Temperatura (°C o °F)**

- Los datos del sensor se actualizan cada **5 segundos**, permitiendo optimizar el rendimiento y reducir la carga de
  procesamiento.

- Si se ha configurado sensores de presión mediante la **integración con Home Assistant**, y está vinculado al Tilt
  seleccionado, se mostrará también una **lectura de presión** junto a la densidad y temperatura.

<div align="center">
  Pantalla de TiltSense con presión
</div>

### 💤 Modo reposo

- La pantalla entra automáticamente en **modo reposo** tras **2 minutos de inactividad** para reducir el consumo
  energético.
- Para reactivarla, simplemente **toca en cualquier parte** de la pantalla. El dispositivo volverá a mostrar la misma
  pantalla en la
  que se encontraba anteriormente.

### 📴 Activar / Desactivar Dispositivos Tilt

- Al tocar la **zona inferior** de la pantalla se alterna entre **activar o desactivar** el Tilt seleccionado.
- Cuando está desactivado:
    - El Tilt deja de enviar actualizaciones hacia las integraciones.
    - No se envían datos a Brewfather ni a Home Assistant.
    - La interfaz muestra el color del Tilt en **tono gris** para indicar que está inactivo.

<div align="center">
  Pantalla de TiltSense con Tilt desactivado
</div>

Esta función es útil cuando un Tilt no está en uso o está apagado, ayudando a reducir la carga del sistema.

---

## 🔁 Integración con Brewfather

- Cuando la integración con Brewfather está habilitada y configurada, TiltSense envía los datos del sensor cada **15
  minutos**, siguiendo las especificaciones oficiales de Brewfather.

---

## 🏠 Integración con Home Assistant

Si está activada la integración con Home Assistant, TiltSense aprovecha las capacidades nativas de  
[ESPHome](https://esphome.io/) para enviar datos de los sensores en tiempo real directamente a Home Assistant.

Esto permite a los usuarios:

- **Monitorizar la fermentación en tiempo real** desde los paneles de Home Assistant.
- **Crear automatizaciones o alertas** basadas en lecturas de densidad, temperatura o presión.
- **Combinar los datos del Tilt con otros sensores**, como sondas de temperatura, sensores de presión o enchufes
  inteligentes.

No es necesaria ninguna configuración adicional en el dispositivo más allá de habilitar la integración de ESPHome en
Home Assistant: todos los datos del sensor estarán disponibles como entidades nativas.

---

TiltSense está diseñado para ser simple e intuitivo — permitiendo a los cerveceros obtener información del estado de sus
fermentaciones de un vistazo, con una interacción mínima.

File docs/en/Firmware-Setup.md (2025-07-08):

---
title: Firmware Configuration and Installation
description: Learn how to generate and install custom firmware for your TiltSense device using the official web-based firmware builder.
icon: material/memory
---

# 🔧 Firmware Configuration and Installation

TiltSense provides an official **web-based Firmware Builder** that allows you to easily generate custom firmware for
your device — without needing to write or modify any code.

The application prepares a custom version of the firmware for your device based on your choices, checks that everything
is correctly filled in, and gives you a file ready to install.

---

## 🌐 What is the Firmware Builder?

The Firmware Builder is a simple and guided web tool that helps you create a personalized firmware for your TiltSense
device, based on your preferences and setup.

With just a few steps, you can:

- Select one or more Tilt hydrometers to monitor.
- Configure each Tilt by color, and mark if it’s a Tilt Pro.
- Set up your Wi-Fi network so TiltSense can connect and send data.
- Enable integration with Brewfather to track your fermentation automatically.
- Enable integration with Home Assistant for home automation and live monitoring.
- Add support for a pressure sensor, if available in your setup.

Once configured, the tool will generate a custom firmware file that includes everything you need — and you can either
download it for manual use or let the builder compile it for you, ready to install.

You can access the builder here:  
👉 **[Firmware Builder](https://bananabrewery.github.io/TiltSenseFirmwareBuilder)**

[https://bananabrewery.github.io/TiltSenseFirmwareBuilder](https://bananabrewery.github.io/TiltSenseFirmwareBuilder)

---

## 🧩 Step-by-Step Configuration

### Select Tilt Devices (Required)

To use TiltSense, you must select **at least one Tilt hydrometer**.

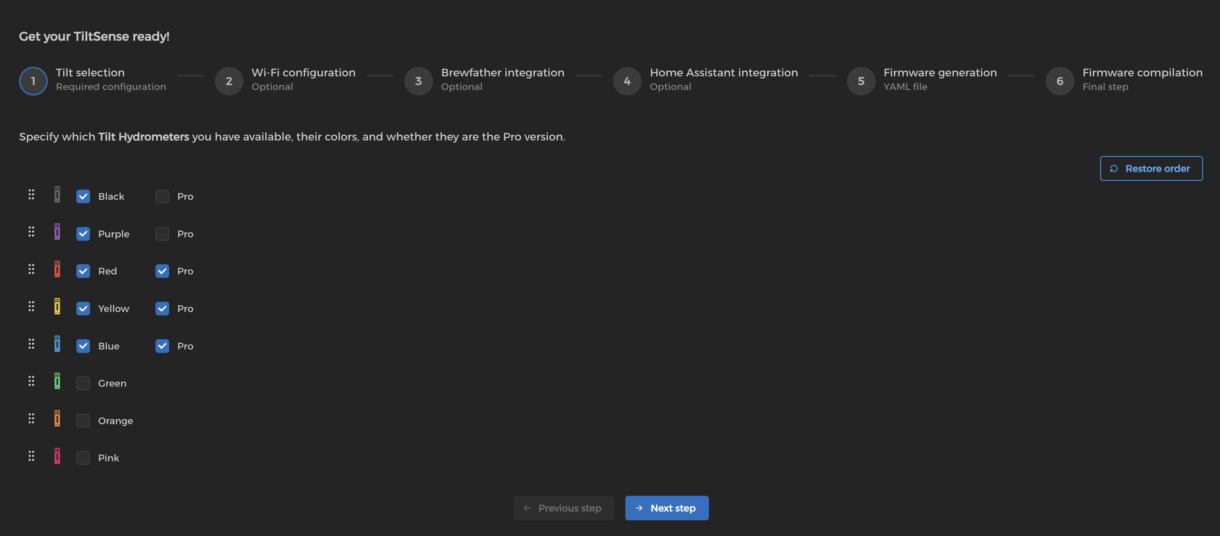
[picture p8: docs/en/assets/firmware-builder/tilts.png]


For each Tilt you enable:

- You can specify whether it’s a **Tilt Pro** or a standard model.
- If you have multiple Tilts, you can **arrange their order** using drag-and-drop. This defines the order in which they
  will appear on the TiltSense screen.
- A **"Restore Order"** button is available to reset the original sorting if needed.

Not enabled Tilt devices will not appear on the screen or send any data, which helps improve performance and reduce
unnecessary communication.

---

### Wi-Fi Configuration (Optional)

You can provide your **Wi-Fi SSID and password** to allow TiltSense to connect to your local network.

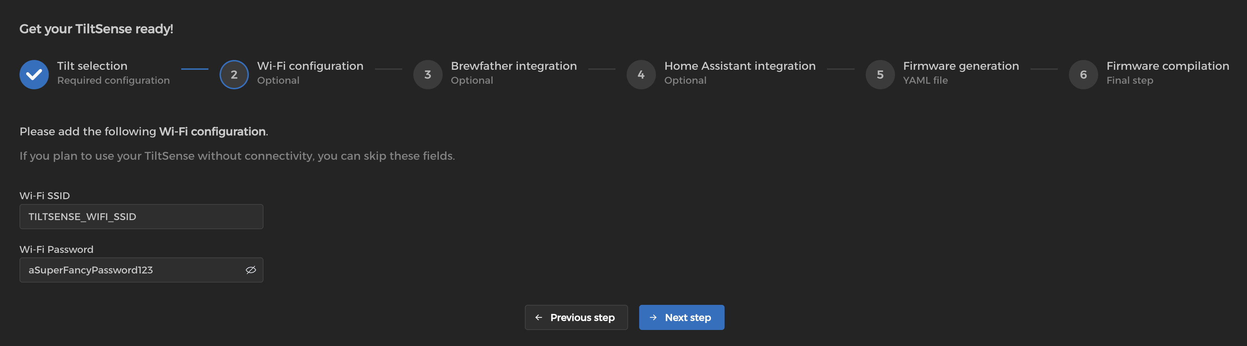
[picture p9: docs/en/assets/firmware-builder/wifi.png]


This is required for:

- Accessing the **web interface** at [`http://tiltsense.local`](http://tiltsense.local)
- Sending data to Brewfather or Home Assistant

If omitted, TiltSense will operate in offline mode.

---

### Brewfather Integration (Optional)

Enable this option if you want TiltSense to send your fermentation data directly to your **Brewfather account**.

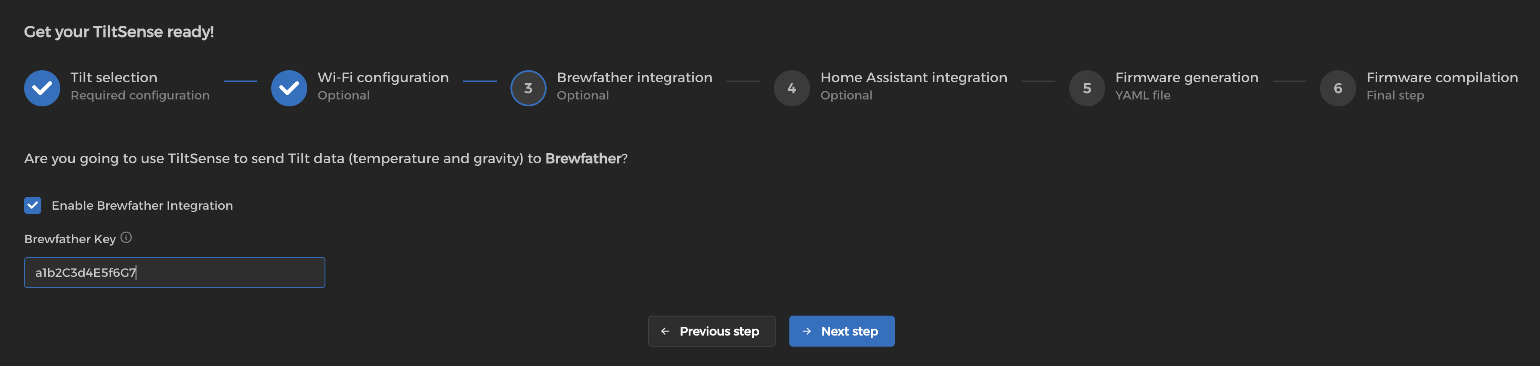
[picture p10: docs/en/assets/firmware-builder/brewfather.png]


To set it up, you’ll need to provide:

- Your **Custom Stream ID** — this is the API key used to send data to Brewfather (e.g., `a1b2C3d4E5f6G7`).

TiltSense will send the following readings:

- **Gravity**
- **Temperature**
- **Pressure** (if a pressure sensor is configured and enabled)

Readings are sent every **15 minutes**, following Brewfather’s official specification.

> 🔗 You can find your Custom Stream ID and learn how to use it in the official Brewfather documentation:  
> [docs.brewfather.app/integrations/custom-stream](https://docs.brewfather.app/integrations/custom-stream)

---

### Home Assistant Integration (Optional)

When enabled, TiltSense connects to your local network and integrates directly with **Home Assistant** as a native
ESPHome node.

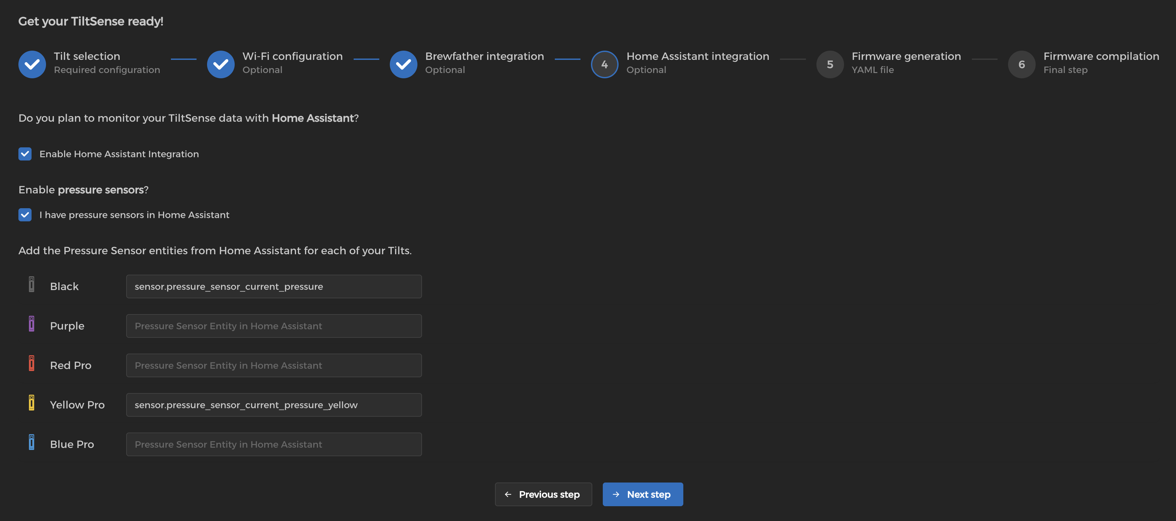
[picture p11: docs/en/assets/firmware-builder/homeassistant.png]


TiltSense exposes the following entities to Home Assistant:

- **Gravity** and **Temperature** readings for each enabled Tilt.
- **Switches** to enable or disable each Tilt remotely — just like using the device’s touchscreen.
- **Battery voltage** and an estimated **battery charge percentage**.

This allows for full monitoring and control of your fermentation process directly from Home Assistant.

> 🧠 No advanced setup is required — just add TiltSense through the standard **ESPHome integration** in Home Assistant.

---

### Pressure Sensor Integration - Home Assistant (Optional)

If you enable the Home Assistant integration, you can also link **external pressure sensors** to TiltSense.



Once this option is activated:

- A new section will appear showing the list of **enabled Tilt hydrometers**.
- For each active Tilt, you can enter the corresponding **Home Assistant entity ID** of a pressure sensor (e.g.,
  `sensor.pressure_sensor_current_pressure`).
- These sensors must already exist and be available in your Home Assistant setup.

By providing a pressure entity for a given Tilt:

- **Live pressure readings** will be displayed alongside gravity and temperature on the TiltSense screen.
- The pressure value will also be **sent to Brewfather** every 15 minutes, if Brewfather integration is enabled.

> 🧠 This setup allows advanced fermentation profiling under pressure, combining gravity, temperature, and pressure in
> one view.

---

## ✅ Configuration Validation

Before generating the firmware, the application presents a **Configuration Summary** showing all selected options.

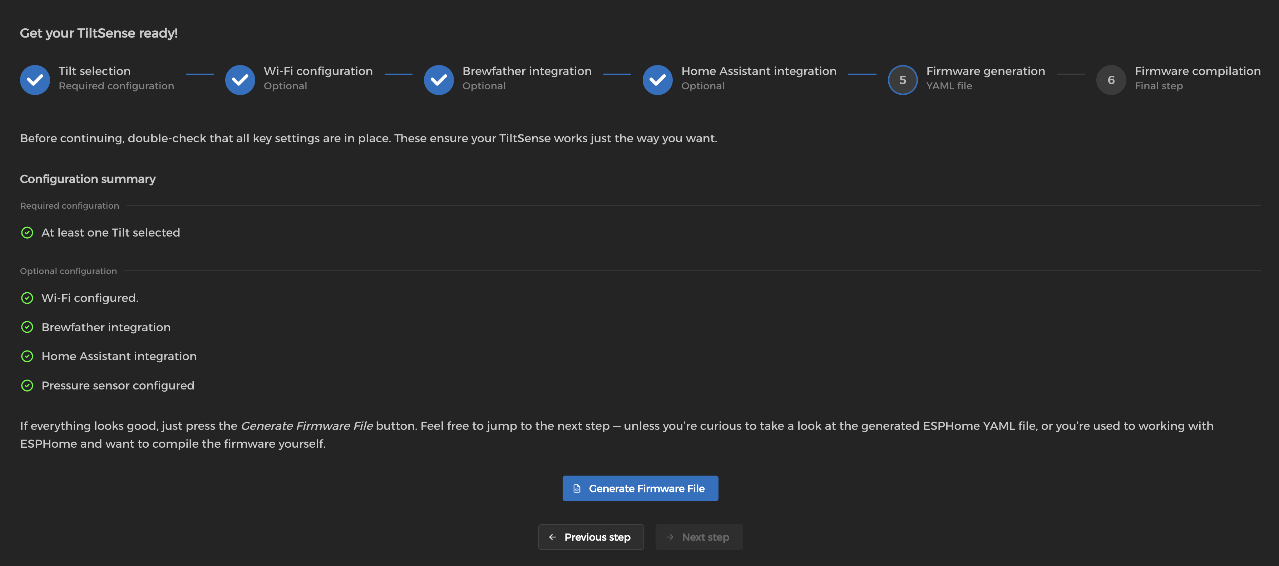
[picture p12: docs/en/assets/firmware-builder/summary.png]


This summary serves as a final validation step to ensure consistency across your setup. For example:

- All required fields must be filled.
- Wi-Fi must be configured if Brewfather or Home Assistant integration is enabled.
- There should be no conflicting or incomplete settings.

Once the configuration passes validation:

- The **"Generate Firmware File"** button will be enabled.
- A fully tailored **ESPHome YAML file** will be created based on your setup.

The YAML file is shown in a built-in code viewer, allowing you to:

- **Preview** the complete configuration.
- **Copy** the YAML if you want to compile and flash the firmware using your own ESPHome setup.
- **Download** the file for offline use or manual installation.

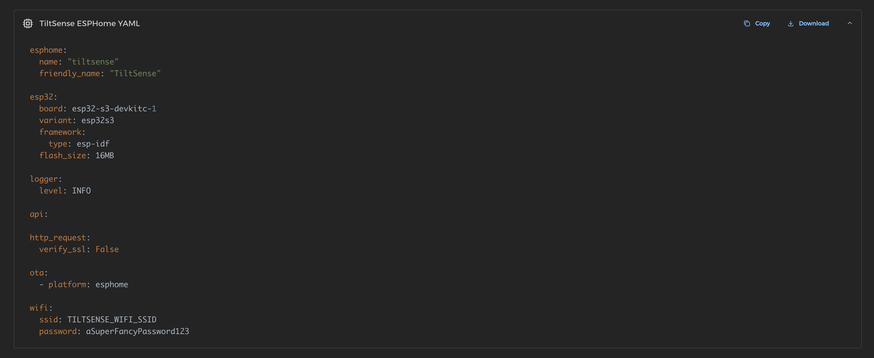
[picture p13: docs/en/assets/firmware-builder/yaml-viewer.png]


> 🛠️ Advanced users can manage everything manually with ESPHome.  
> For everyone else, you can continue to the next step and let the app **compile the firmware for you automatically**.

---

## 🛠️ Build and Download Firmware

Once your configuration has been validated successfully, you can proceed to compile the firmware.

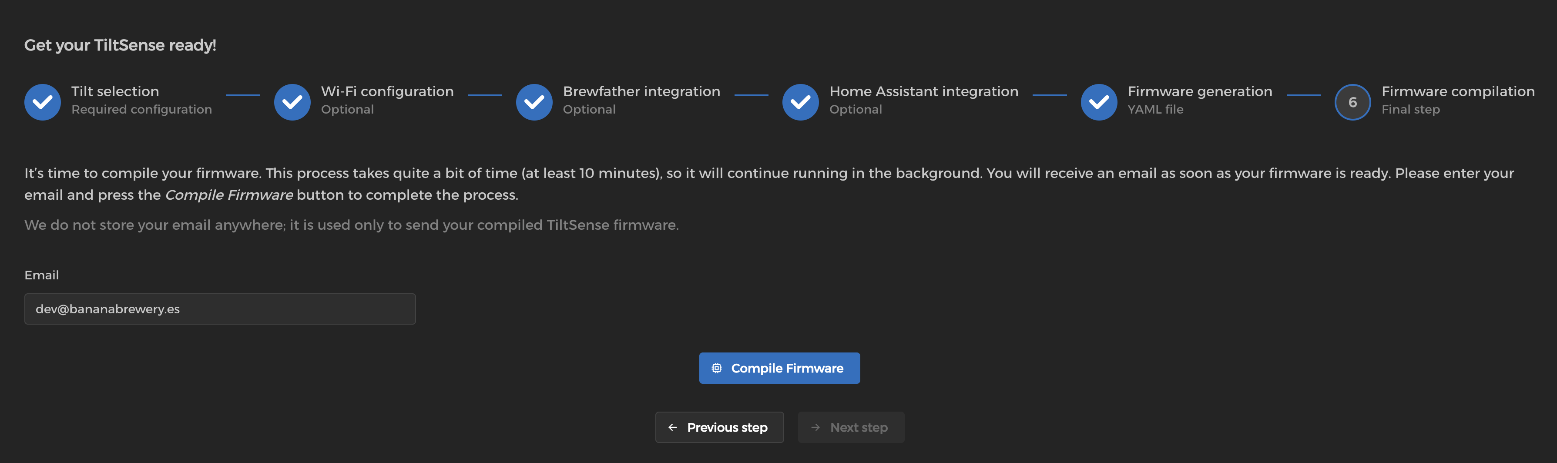
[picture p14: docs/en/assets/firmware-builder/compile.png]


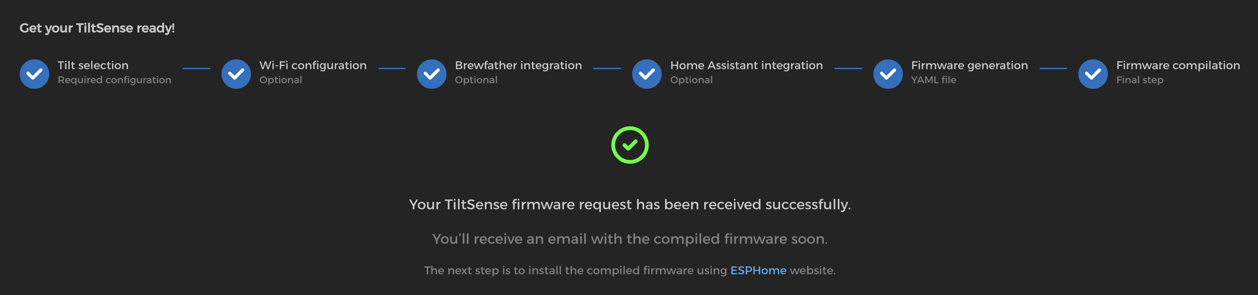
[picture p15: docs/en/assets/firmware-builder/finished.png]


### How It Works

- The app will guide you to the **Firmware Compilation** section.
- Firmware compilation is a resource-intensive process and may take several minutes (up to **10 minutes**).
- To ensure a smooth experience, the firmware is **compiled in the background**.
- Once ready, the compiled firmware file (`firmware.factory.bin`) will be sent to your **email inbox**.

### Why We Ask for Your Email

- Your **email address is required** to send you the compiled firmware.
- The address is **not stored or saved** — it's used only once to deliver your custom firmware.
- Without a valid email, the compilation process cannot be completed.

### Build Policy

To ensure fair access and optimal resource usage:

- Each user can build **one firmware per hour**.
- Multiple build requests are handled via a **first-in, first-out queue**.

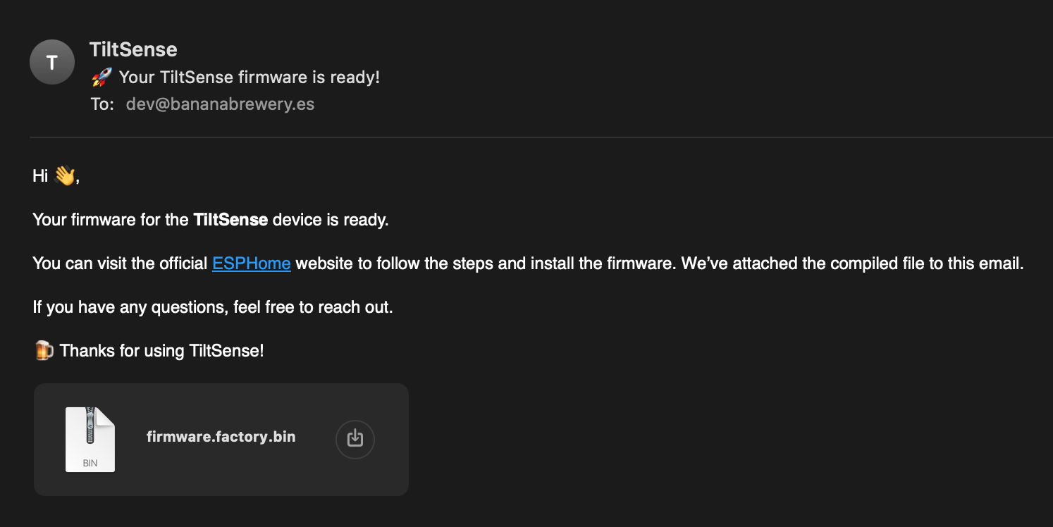
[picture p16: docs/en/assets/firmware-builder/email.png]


You’ll receive an email with the file attached as soon as your firmware is ready.

> 📩 Check your spam folder if you don’t receive the email after 30 minutes.

The final step is to **install the firmware** on your TiltSense device — see the next section for instructions.

---

## ⚡ How to Flash the Firmware

To flash the firmware:

1. Connect the TiltSense device to your computer using a **USB-C cable**.
2. Open [ESPHome Web Flasher](https://esphome.github.io/esphome-web/).
3. Click **"Connect"** and select the ESP32-S3 device.
4. Upload the `.bin` file you downloaded from the builder.

> 💡 If the flashing fails, you may need to **hold the BOOT button** on your ESP32-S3 board while connecting.

---

## 🧯 Troubleshooting

### "Timed out waiting for packet header"

- Make sure the USB-C cable supports data (not just charging).
- Try holding the BOOT button while clicking "Connect".

### No Wi-Fi connection after flashing

- Rebuild the firmware ensuring Wi-Fi credentials are correct.
- Make sure your network is 2.4GHz (ESP32-S3 does not support 5GHz).

### Tilt data not showing up

- Make sure the Tilt is active and transmitting.
- Ensure the selected color in the firmware matches the physical device.
- Check that the Tilt is enabled on the screen (not grayed out).

---

For further support, visit the [GitHub Discussions](https://github.com/bananabrewery/TiltSense/discussions) or open
an [Issue](https://github.com/bananabrewery/TiltSense/issues).

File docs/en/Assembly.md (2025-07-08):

---
title: Assembly Instructions
description: Step-by-step guide to assembling the TiltSense device, including board installation, battery setup, and case closure.
icon: material/screwdriver
---

# Assembly Instructions

This section guides you through the complete assembly process of the TiltSense hardware. The 3D-printed enclosure is
designed for a precise and tool-light build process. With just a few basic steps, your device will be ready for firmware
installation and brewing use.

> 🛑 **Important:** Before starting, make sure you've reviewed the [Hardware Requirements](Hardware.md) and have all the
> components ready.

---

## Step-by-Step Instructions

### 1. Install the Heat-Set Inserts

Using a soldering iron, carefully install the **four brass heat-set inserts** vertically into the designated holes in
the base of the 3D-printed case. Apply light downward pressure until the insert is flush with the plastic. Allow to cool
before proceeding.

> 🔥 Tip: Use a heat-set insert tip or a flat soldering iron head for best results.

---

### 2. Place the ESP32-S3 Board

Insert the ESP32-S3 board into the enclosure, aligning the **USB-C port** with the matching opening on the case. Gently
press the board until it seats fully at the bottom, ensuring the **round display is perfectly aligned and flush with the
front bezel**.

---

### 3. (Optional) Connect and Place the Battery

If you're using a LiPo battery, connect it to the JST 1.25mm socket on the board, verifying the **polarity** before
connecting. Position the battery above the ESP32-S3 board, ensuring it does not obstruct the USB-C connector.

---

### 4. (Optional) Add Foam for Battery Stability

To prevent movement during handling, place a small piece of **soft, lightweight foam** alongside or on top of the
battery. This provides gentle pressure to keep the battery stable without stressing the wiring.

---

### 5. Attach the Top Cover

Align the top lid with the case and gently press it into place. The cover is designed to **secure the ESP32-S3 board
from the USB-C port side**, ensuring it remains fixed even during movement.

---

### 6. Secure the Case with Screws

Insert the **M2x5mm screws** into the mounting holes and tighten until snug. Do not overtighten to avoid damaging the
plastic or stripping the inserts.

---

## Done!

Your TiltSense device is now fully assembled and ready for firmware flashing and configuration. Proceed to
the [Firmware Setup](Firmware-Setup.md) section to complete the process.

> 🧪 Before closing the case, you may want to flash the firmware using the USB-C port to avoid reopening the enclosure.
> During the flashing process, you might need to press and hold the Boot button on the ESP32-S3 board to enable
> programming mode.

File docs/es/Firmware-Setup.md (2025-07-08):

---
title: Configuración e Instalación del Firmware
description: Aprende a generar e instalar firmware personalizado para tu dispositivo TiltSense usando el generador oficial basado en la web.
icon: material/memory
---

# 🔧 Configuración e Instalación del Firmware

TiltSense proporciona un **Generador de Firmware basado en la web** que te permite crear firmware personalizado para tu
dispositivo de forma sencilla, sin necesidad de escribir ni modificar código.

La aplicación prepara una versión personalizada del firmware según tu parametrización, verifica que todo esté bien
configurado y te entrega un archivo listo para instalar en tu dispositivo TiltSense.

---

## 🌐 ¿Qué es el Generador de Firmware?

Es una herramienta web simple que te permite crear un firmware personalizado para tu dispositivo TiltSense de una manera
guiada por pasos, según tus preferencias y configuración.

Siguiendo los pasos, serás capaz de:

- Seleccionar uno o más Tilt para monitorizar con tu TiltSense.
- Configurar cada Tilt por color e indicar si es un modelo Pro.
- Configurar tu red Wi-Fi para que TiltSense pueda conectarse y enviar datos.
- Activar la integración con Brewfather para registrar en tus fermentaciones.
- Activar la integración con Home Assistant para automatización y monitorización en vivo.
- Añadir soporte para sensores de presión, si está disponible en tu configuración.

Una vez configurado, la herramienta genera un archivo de firmware personalizado que puedes descargar o dejar que el
generador lo compile por ti.

Puedes acceder al generador aquí:  
👉 **[Firmware Builder](https://bananabrewery.github.io/TiltSenseFirmwareBuilder)**

[https://bananabrewery.github.io/TiltSenseFirmwareBuilder](https://bananabrewery.github.io/TiltSenseFirmwareBuilder)

---

## 🧩 Configuración Paso a Paso

### Seleccionar Dispositivos Tilt (Obligatorio)

Para usar TiltSense, debes seleccionar **al menos un Tilt**.

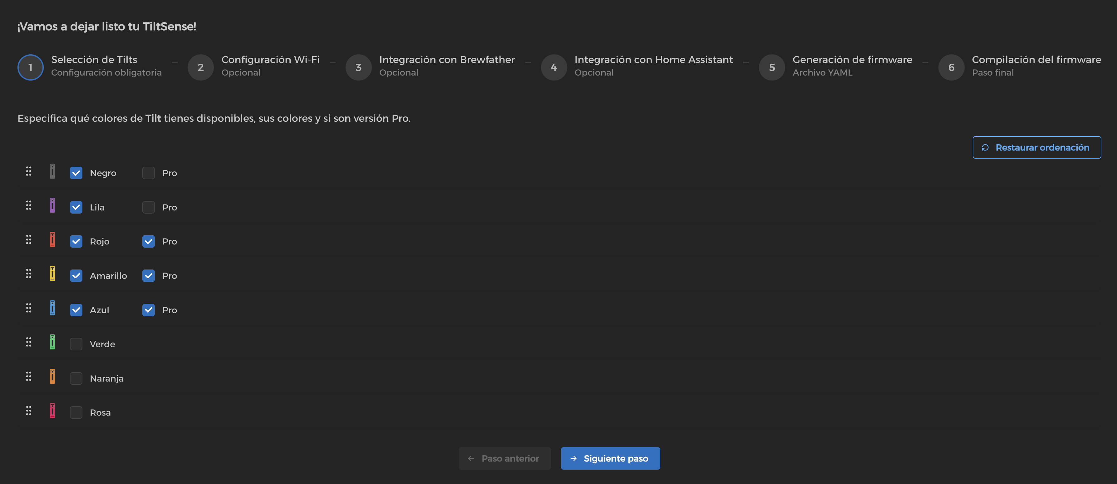
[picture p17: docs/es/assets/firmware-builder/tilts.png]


Por cada Tilt que habilites:

- Puedes indicar si es un **Tilt Pro** o estándar.
- Si tienes varios Tilts, puedes **ordenarlos** arrastrando y soltando. Este orden define la secuencia en la que
  aparecerán en la pantalla de TiltSense.
- Hay un botón **"Restaurar Ordenación"** para restablecer la ordenación original.

Los Tilts no habilitados no aparecerán en pantalla ni enviarán datos, lo cual mejora el rendimiento y reduce
comunicaciones innecesarias.

---

### Configuración Wi-Fi (Opcional)

Puedes proporcionar tu **SSID y contraseña Wi-Fi** para que TiltSense se conecte a tu red local.

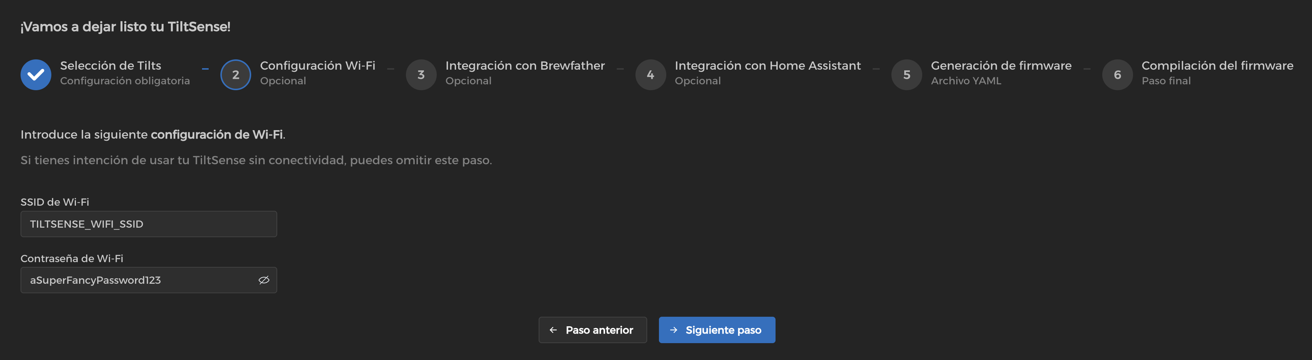
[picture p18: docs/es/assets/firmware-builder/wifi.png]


Esto es necesario para:

- Acceder a la **interfaz web** en [`http://tiltsense.local`](http://tiltsense.local)
- Enviar datos a Brewfather o Home Assistant

Si lo omites, TiltSense funcionará en modo sin conexión.

---

### Integración con Brewfather (Opcional)

Activa esta opción si deseas que TiltSense envíe los datos a tu **cuenta de Brewfather**.

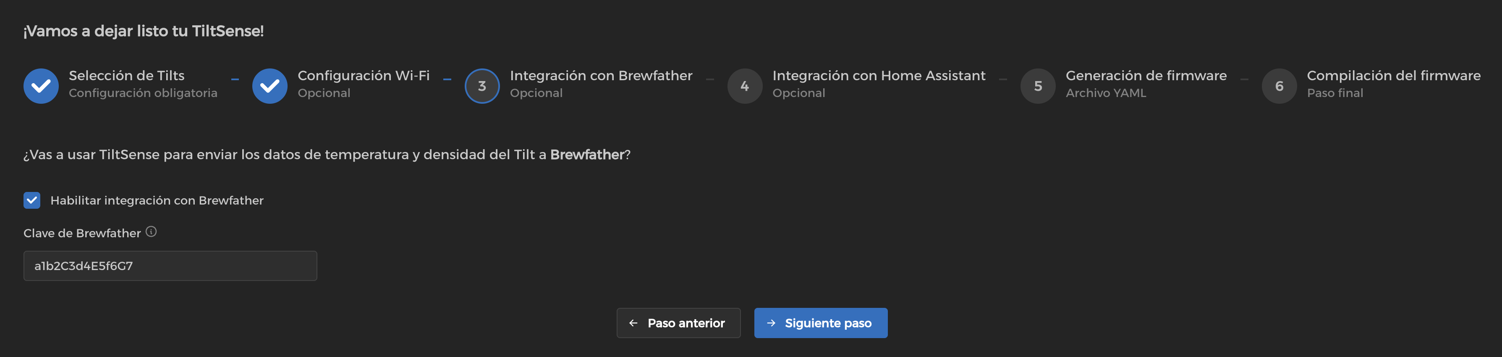
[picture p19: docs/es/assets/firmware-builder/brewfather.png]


Para configurarlo, necesitas proporcionar:

- Tu **Custom Stream ID** — clave API usada para enviar datos a Brewfather (ej. `a1b2C3d4E5f6G7`).

TiltSense enviará:

- **Densidad**
- **Temperatura**
- **Presión** (si hay un sensor configurado y habilitado)

Los datos se envían cada **15 minutos**, siguiendo las especificaciones oficiales de Brewfather.

> 🔗 Puedes encontrar tu Custom Stream ID y aprender cómo utilizarla en la documentación
> oficial: [docs.brewfather.app/integrations/custom-stream](https://docs.brewfather.app/integrations/custom-stream)

---

### Integración con Home Assistant (Opcional)

Si se activa, TiltSense se conecta a la red local e **integra con Home Assistant** como un nodo nativo de ESPHome.

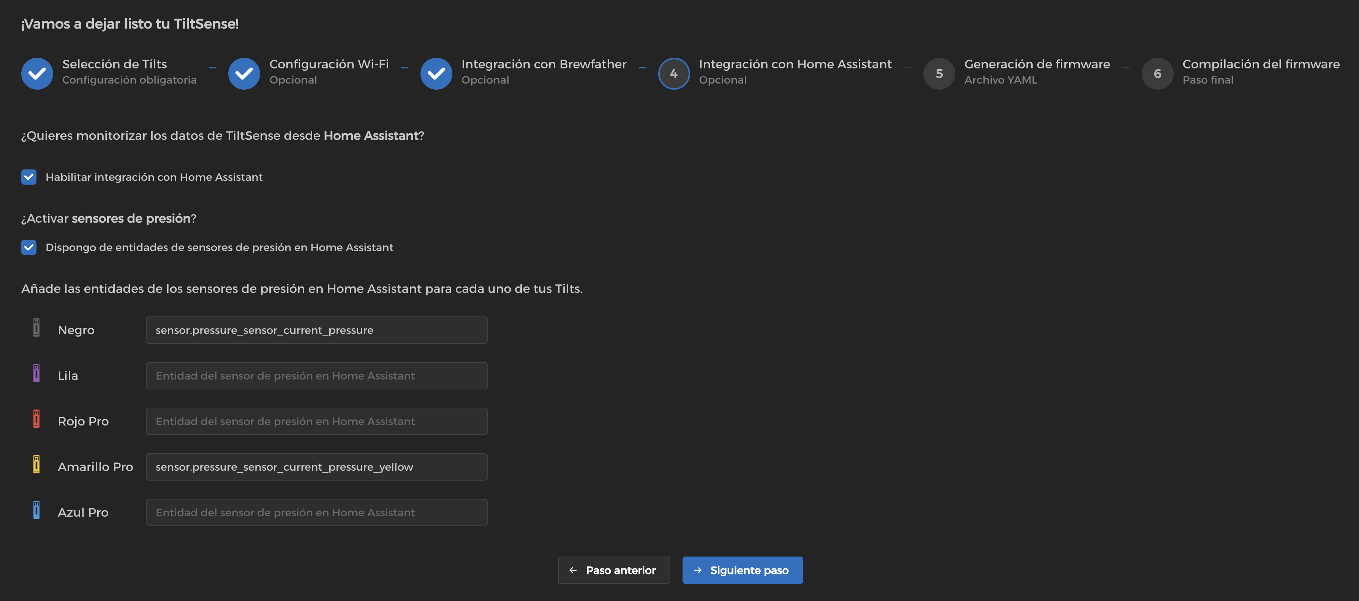
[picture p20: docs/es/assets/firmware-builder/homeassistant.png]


TiltSense expone las siguientes entidades a Home Assistant:

- Lecturas de **densidad** y **temperatura** para cada Tilt habilitado.
- **Interruptores** para activar o desactivar Tilts remotamente — Del mismo modo que si lo haces mediante la pantalla
  táctil.
- **Tensión de la batería** y estimación del **porcentaje de carga**.

Esto permite la monitorización y control total de tu proceso de fermentación directamente desde Home Assistant.

> 🧠 No se requiere ninguna configuración avanzada — solo añade TiltSense a través de la integración ESPHome en Home
> Assistant.

---

### Sensor de Presión - Home Assistant (Opcional)

Si activas la integración con Home Assistant, puedes vincular **sensores de presión externos** en TiltSense.



Al activar esta opción:

- Aparecerá una sección nueva con los Tilt habilitados previamente.
- Para cada uno de ellos, puedes introducir el **ID de la entidad** del sensor de presión (ej.
  `sensor.pressure_sensor_current_pressure`).
- Estas entidades deben existir y estar disponibles previamente en Home Assistant.

Asignando un sensor de presióna un Tilt permite:

- Mostrar la **presión en vivo** junto con la temperatura y la densidad en la pantalla.
- El valor de la presión se enviará a Brewfather cada 15 minutos (si está habilitada esa integración).

> 🧠 Esta configuración permite monitorizar de manera avanzada el proceso de fermentación bajo presión, combinando la
> densidad, temperatura y presión en un mismo origen de datos.

---

## ✅ Validación de la Configuración

Antes de generar el firmware, la aplicación muestra un **Resumen de configuración** con todas las opciones
seleccionadas.

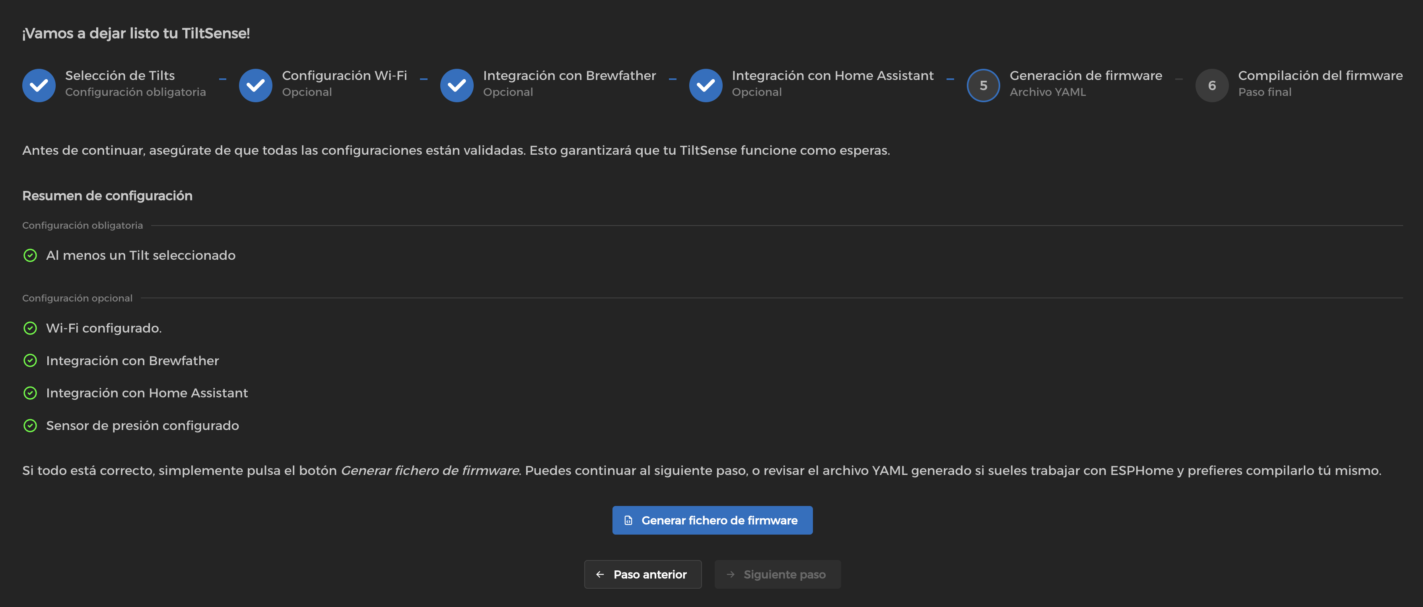
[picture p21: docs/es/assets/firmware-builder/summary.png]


Este resumen sirve como validación final para asegurar la consistencia del setup. Por ejemplo:

- Que los campos requeridos estén rellenados.
- Que Wi-Fi esté configurado correctamente si usas las integraciones de Brewfather o Home Assistant.
- Que no haya conflictos o campos incompletos en la configuración.

Una vez el proceso queda validado:

- Se activará el botón **"Generar fichero de firmware"**.
- Se crea un archivo YAML de ESPHome completo y adaptado a tu configuración.

El fichero YAML se puede visualizar en un visor de código integrado que permite:

- **Previsualizar** la configuración completa.
- **Copiar** el YAML por si quieres compilar e instalar el firmware mediante ESPHome por tu cuenta.
- **Descargar** el archivo para instalarlo manualmente o echar un vistazo en offline.

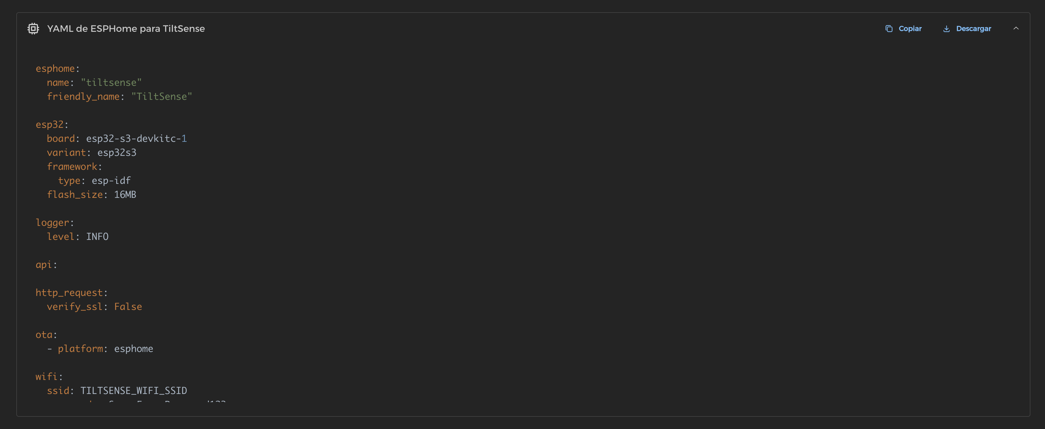
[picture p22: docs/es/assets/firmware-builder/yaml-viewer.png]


> 🛠️ Los usuarios avanzados pueden usar su instancia de ESPHome directamente. Para el resto, continua al próximo paso y
> deja que la aplicación **compile el firmwpare por ti automáticamente**.

---

## 🛠️ Compilar y Descargar el Firmware

Una vez tu configuración ha sido validada, puedes proceder con la compilación de tu firmware.

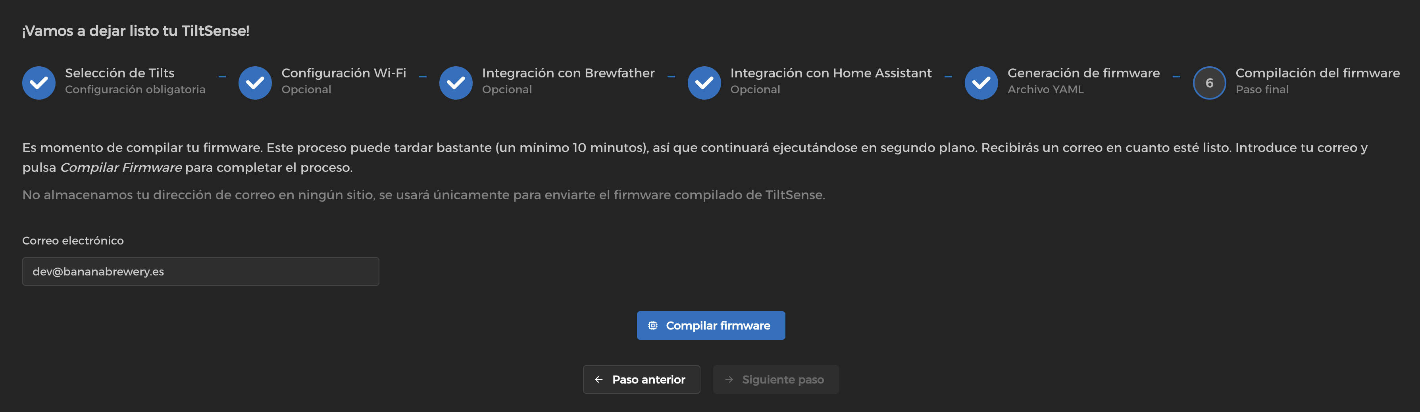
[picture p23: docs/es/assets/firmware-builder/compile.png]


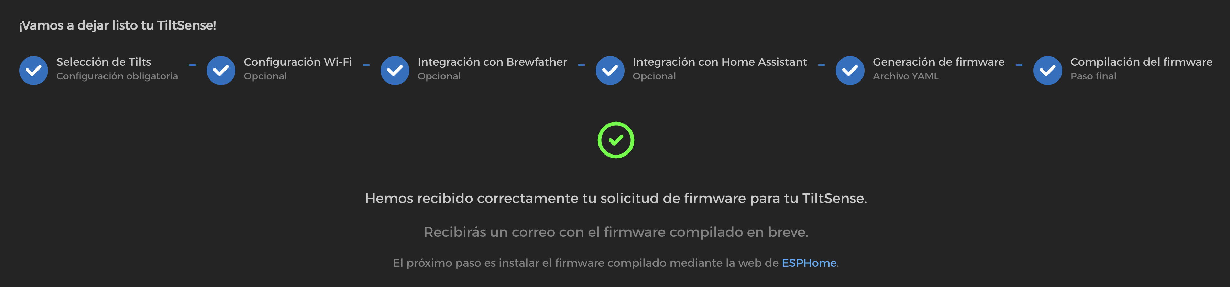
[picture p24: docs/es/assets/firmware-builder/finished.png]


### Cómo Funciona

- La app te guiará a la sección de **Compilación del firmware**.
- La compilación del firmware requiere de grandes recursos para procesar y puede tardar varios minutos (hasta **10
  minutos**).
- Para asegurar la operativa, la compilación se realizará **en segundo plano**.
- Una vez esté todo listo, recibirás el archivo de firmware compilado (`firmware.factory.bin`) mediante un **correo
  electrónico** directo en tu buzón.

### Por Qué se Solicita tu Email

- Tu dirección de correo electrónico es requerido para hacerte llegar el firmware compilado.
- Tu email **no se guarda ni se almacena** — se usa únicamente una vez para entregar tu firmware personalizado.
- Sin introducir un email válido, el proceso de compilación no se puede completar.

### Política de Compilación

Para asegurar un uso adecuado y óptimo de los recursos:

- Cada usuario puede compilar **una firmware por hora**.
- Si hay múltiples peticiones se compilación se gestionarán mediante una cola por **orden de llegada**.

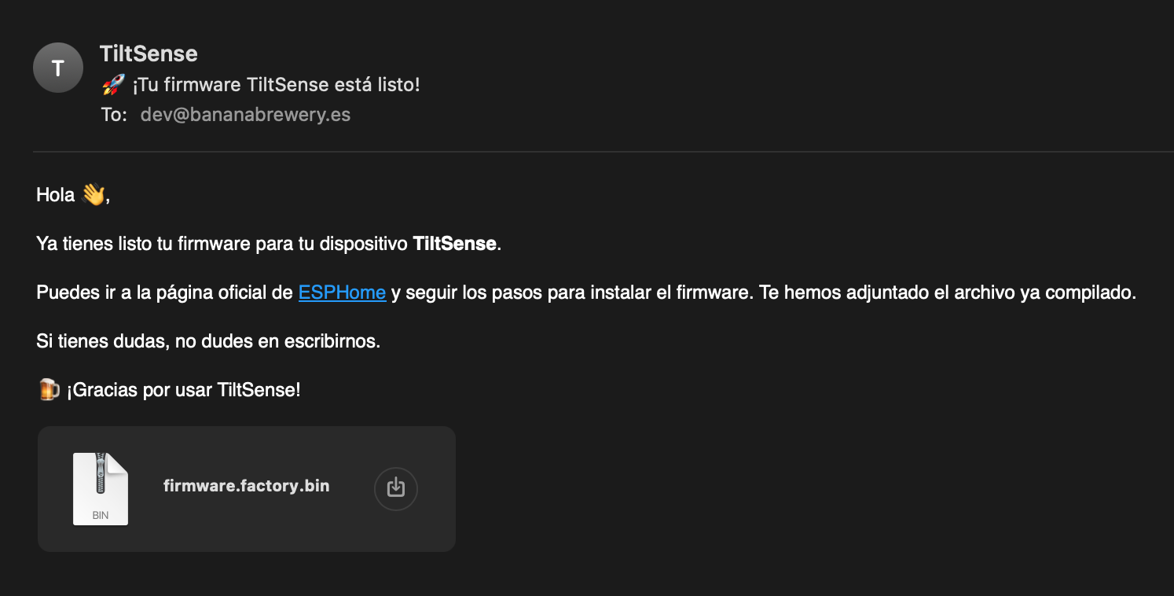
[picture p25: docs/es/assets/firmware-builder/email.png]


Recibirás un email con el fichero del firmware compilado adjunto tan pronto como haya terminado el proceso.

> 📩 Revisa tu carpeta de spam si no recibes el correo después de 30 minutos.

El paso final es **instalar el firmware** en tu dispositivo TiltSense. Sigue a la próxima sección para más información.

---

## ⚡ Cómo Flashear el Firmware

Para instalar el firmware:

1. Conecta el dispositivo TiltSense por **USB-C** a tu ordenador.
2. Abre [ESPHome Web Flasher](https://esphome.github.io/esphome-web/).
3. Haz clic en **"Connect"** y selecciona el dispositivo ESP32-S3.
4. Carga el archivo `.bin` descargado en el anterior paso.

> 💡 Si el proceso de instalación falla, puede que debas **mantener pulsado el botón de BOOT** de tu placa ESP32-S3
> mientras lo conectas al ordenador.

---

## 🧯 Solución de Problemas

### "Timed out waiting for packet header"

- Asegúrate de que el cable USB-C **sirve para datos** y no se trata de un cable únicamente para carga.
- Mantén pulsado **BOOT** mientras haces clic en "Connect".

### No hay conexión Wi-Fi tras flashear

- Recompila el firmware asegurando que Wi-Fi está bien escrito.
- Verifica que tu red sea de **2.4GHz** (ESP32-S3 no soporta redes 5GHz).

### No aparecen los datos del Tilt

- Asegúrate de que el Tilt está activo y transmitiendo.
- Verifica que el color del dispositivo físico coincida con el configurado en el firmware.
- Comprueba que el Tilt esté habilitado en la pantalla (no se muestra en color gris).

---
Para cualquier soporte adicional, visita las [Discusiones en GitHub](https://github.com/bananabrewery/TiltSense/discussions) o
abre un [Issue](https://github.com/bananabrewery/TiltSense/issues).

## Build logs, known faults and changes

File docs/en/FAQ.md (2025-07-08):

---
title: Frequently Asked Questions (FAQ)
description: Answers to common questions about using, assembling, and configuring TiltSense.
icon: material/help-circle
---

# Frequently Asked Questions (FAQ)

Here you’ll find answers to the most common questions about TiltSense. This section will grow over time as the community provides feedback.

---

### 📦 What is TiltSense?

TiltSense is an open-source fermentation monitoring system based on ESP32-S3, designed to work with Tilt Hydrometers and other sensors like pressure probes. It combines real-time data logging, local visualization, and integration with platforms like Brewfather and Home Assistant.

---

### ⚙️ Can I use TiltSense without a Tilt Hydrometer?

No. TiltSense is specifically designed to read data from Tilt Hydrometers. However, it can also integrate pressure sensors for enhanced fermentation tracking when used **in addition to** Tilt data.

---

### 🔋 How long does the internal battery last?

The internal battery is designed as a backup/emergency power source. It typically lasts **around 45 minutes**, making it ideal for safely moving the device between setups or as a small UPS in case of power loss.

---

### 🧲 How is the device mounted?

TiltSense is housed in a custom 3D-printed enclosure with an embedded **20mm neodymium magnet**. This allows for easy mounting on stainless steel fermenters or fridge walls.

---

### 🧪 Do I need to keep TiltSense connected all the time?

Yes, for full fermentation tracking, you should keep TiltSense **powered via USB**. While the battery can provide short-term operation, long-term use requires a stable power supply.

---

### 🧰 Do I need to flash the firmware before assembling the case?

It is **strongly recommended** to flash the firmware **before closing the enclosure**, as the USB-C port and Boot button may be harder to access afterward.

---

### 🌐 Can I access TiltSense from my browser?

Yes. TiltSense includes a **built-in web interface** served locally over Wi-Fi. You can use this interface to view data and configure settings.

---

### 🧠 Do I need to know how to code?

No. The [Firmware Builder](https://example.com) allows you to generate custom firmware without writing code. Advanced users can modify the YAML directly if needed.

---

### 🛠️ Can I contribute to the project?

Absolutely! See the [Development and Contributions](Development.md) section to learn how to get involved.

---

### 🗣️ Where can I ask questions or suggest features?

You can join the discussion on GitHub here:  
👉 [https://github.com/bananabrewery/TiltSense/discussions](https://github.com/bananabrewery/TiltSense/discussions)

You can also report bugs or open feature requests via Issues:  
👉 [https://github.com/bananabrewery/TiltSense/issues](https://github.com/bananabrewery/TiltSense/issues)

---

*Didn't find your question? Let us know via a GitHub discussion, and we’ll update this page accordingly!*

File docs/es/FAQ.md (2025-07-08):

---
title: Preguntas Frecuentes (FAQ)
description: Respuestas a preguntas comunes sobre el uso, montaje y configuración de TiltSense.
icon: material/help-circle
---

# Preguntas Frecuentes (FAQ)

Aquí encontrarás respuestas a las preguntas más comunes sobre TiltSense. Esta sección irá creciendo con el tiempo
gracias a los comentarios de la comunidad.

---

### 📦 ¿Qué es TiltSense?

TiltSense es un sistema de monitorización de fermentaciones de código abierto basado en ESP32-S3, diseñado para
funcionar con Tilt Hydrometers y otros sensores como sensores de presión. Combina registro de datos en tiempo real,
visualización local e integración con plataformas como Brewfather y Home Assistant.

---

### ⚙️ ¿Puedo usar TiltSense sin un Tilt Hydrometer?

No. TiltSense está diseñado específicamente para leer datos de Tilt Hydrometers. Sin embargo, también puede integrar
sensores de presión para un seguimiento más avanzado **complementario** a los datos del Tilt.

---

### 🔋 ¿Cuánto dura la batería interna?

La batería interna está pensada como fuente de energía de respaldo o emergencia. Dura normalmente **unos 45 minutos**,
por lo que es ideal para mover el dispositivo entre setups o como pequeño SAI en caso de corte de energía.

---

### 🧲 ¿Cómo se monta el dispositivo?

TiltSense está alojado en una carcasa personalizada impresa en 3D con un **imán de neodimio de 20 mm** integrado. Esto
permite montarlo fácilmente en fermentadores de acero inoxidable o en las paredes de una nevera.

---

### 🧪 ¿Debo mantener TiltSense siempre conectado?

Sí. Para un seguimiento completo de la fermentación, debes mantener TiltSense **alimentado por USB**. Aunque la batería
permite un funcionamiento temporal, el uso prolongado requiere una fuente de alimentación estable.

---

### 🧰 ¿Debo flashear el firmware antes de montar la carcasa?

Se **recomienda encarecidamente** flashear el firmware **antes de cerrar la carcasa**, ya que el puerto USB-C y el botón
de arranque pueden ser más difíciles de acceder posteriormente.

---

### 🌐 ¿Puedo acceder a TiltSense desde el navegador?

Sí. TiltSense incluye una **interfaz web integrada** que se sirve localmente a través de Wi-Fi. Puedes usar esta
interfaz para ver datos en tiempo real y configurar ajustes.

---

### 🧠 ¿Necesito saber programar?

No. El [Firmware Builder](https://example.com) te permite generar firmware personalizado sin escribir código. Los
usuarios avanzados pueden modificar el YAML directamente si lo desean.

---

### 🛠️ ¿Puedo contribuir al proyecto?

¡Por supuesto! Consulta la sección de [Desarrollo y Contribuciones](Development.md) para saber cómo participar.

---

### 🗣️ ¿Dónde puedo hacer preguntas o proponer mejoras?

Puedes unirte a la discusión en GitHub aquí:  
👉 [https://github.com/bananabrewery/TiltSense/discussions](https://github.com/bananabrewery/TiltSense/discussions)

También puedes reportar errores o abrir solicitudes de mejora en Issues:  
👉 [https://github.com/bananabrewery/TiltSense/issues](https://github.com/bananabrewery/TiltSense/issues)

---

*¿No encontraste tu pregunta? Escríbenos en una discusión de GitHub y actualizaremos esta página.*

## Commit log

2025-06-11 Project structure
    - Adding STL files.
    - Folder structure.
    - Adding BOM.
    [TiltSense Lid v1.3MF]
2025-06-11 3D Files
    - Adding 3D files to the project and reference Makerworld Print Instructions.
2025-06-11 Example YAML
    - Adding a YAML as example.
    - Currently working on a configurable application to generate dynamically the YAML according to each one's configuration.
2025-07-08 - Assembly.md updated.
2025-07-08 - Magnet added.
2025-07-08 - Fix prototypes in dark theme.
2025-07-08 - Firmware-Setup.md finished in Spanish. - Only pending the Assembly Instructions!
2025-07-09 - Assembly.md in Spanish.
2025-07-10 - Remove hardware folder, no longer needed. - Fixed the magnet link, it was not working.
    [TiltSense Lid v1.3MF]
